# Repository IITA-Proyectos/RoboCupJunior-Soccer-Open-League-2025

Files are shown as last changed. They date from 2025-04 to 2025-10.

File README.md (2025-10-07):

# IITA - RoboCupJunior Soccer Open League 2025

Este es el repositorio del equipo IITA para la liga **Open** de RoboCupJunior Soccer 2025.

## Organización del equipo

El equipo se dividió en subgrupos de trabajo para abordar distintas áreas del desarrollo:

grupo **Movilidad**:
 - @Vale15-tb
 - @mijaelb78
 - @vickyT049

grupo **OpenMv**:
 - @3liasCo
 - @rafaelmoya2010
 - @roma1keta

grupo **Dribbler**:
 - @lauri-an
 - @xio02
 - @Aczino593

grupo **Control**:
 - @Leandro284-AR
 - @srmartbr17
 - @ASH101-CODE

Tutores:
 - @Martii3141
 - @sebalander

📌 [Falta agregar un diagrama en bloques del sistema]

---

## Referencias y recursos

### Reglas y recursos oficiales

https://junior.robocup.org/robocupjunior-general-rules/

- 📄 Reglas 2025 (versión HTML):  
  https://robocup-junior.github.io/soccer-rules/2025-soccer-draft-rules/rules.html  
- 📄 Reglas 2025 (PDF):  
  https://robocup-junior.github.io/soccer-rules/master/rules.pdf

Otros links útiles mencionados en ese documento:

- 💬 Foro: https://junior.forum.robocup.org/  
- 💬 Discord: https://robocup-junior.github.io/soccer-rules/discord/  
- 📐 Especificaciones del campo de juego:  
  https://robocup-junior.github.io/soccer-rules/master/field_specification.html

---

### Otros recursos útiles

- 🧠 Recopilación de recursos:  
  https://github.com/robocup-junior/awesome-rcj-soccer  
- 🔧 Kit open source de robótica de fútbol:  
  https://github.com/robot-soccer-kit  
- 📚 Repositorio IITA de recursos en visión y robótica:  
  https://github.com/IITA-Proyectos/resources-robotics-and-machine-vision-resources  
- 🎮 Tutoriales de fútbol virtual de Roboliga Argentina:  
  https://www.virtual.roboliga.ar/1_16_f-tbol.html
- Ejercicios de MAtematicas:
  https://mateslibres.com/
- Balogh, Richard & Obdržálek, David. (2019). Using Finite State Machines in Introductory Robotics: Methods and Applications for Teaching and Learning. 10.1007/978-3-319-97085-1_9.
- Reglas nacionales
  https://docs.google.com/document/d/10VgMxnmTzKQiAOIgHjWHb9KzwLUDc66N0ZvooTC_tL8/edit?tab=t.0

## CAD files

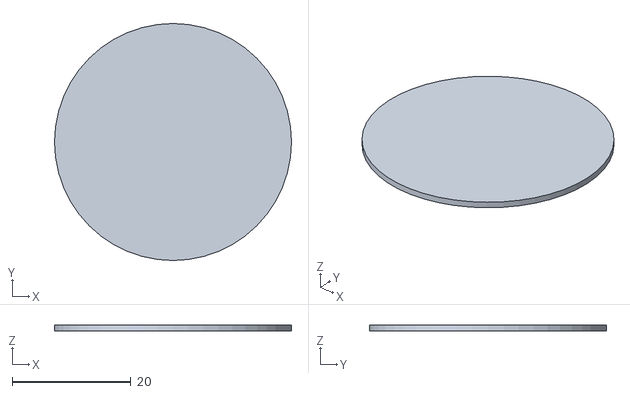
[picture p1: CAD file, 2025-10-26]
Diseño3D/Super Albar-Rottis.stl
40.0 x 40.0 x 1.00

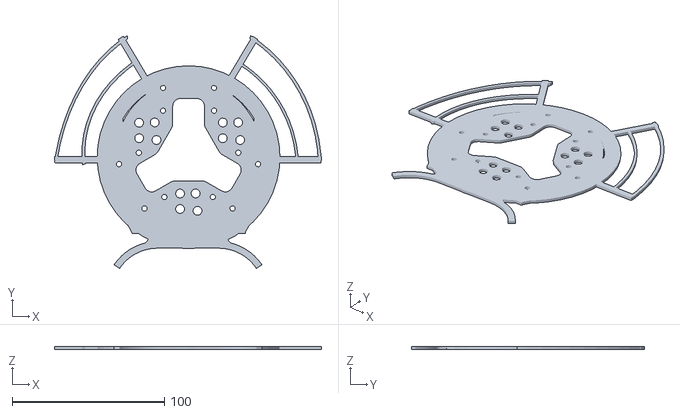
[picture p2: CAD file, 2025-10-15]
Diseño3D/Brilliant Elzing-Amberis.stl
175.2 x 152.9 x 2.00

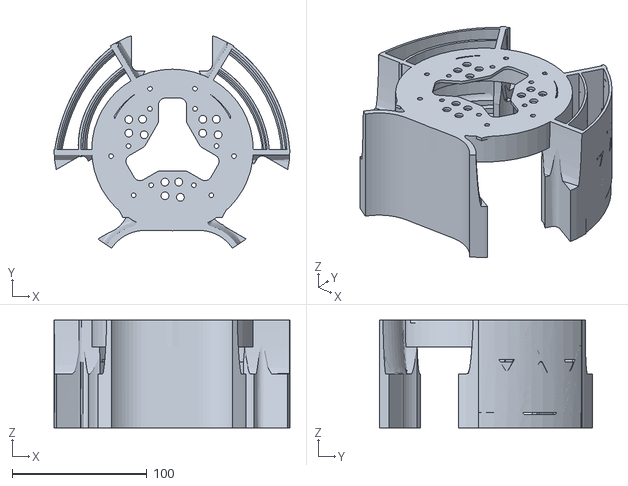
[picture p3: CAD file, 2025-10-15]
Diseño3D/Amazing Wluff (10).stl
175.2 x 157.9 x 80.0

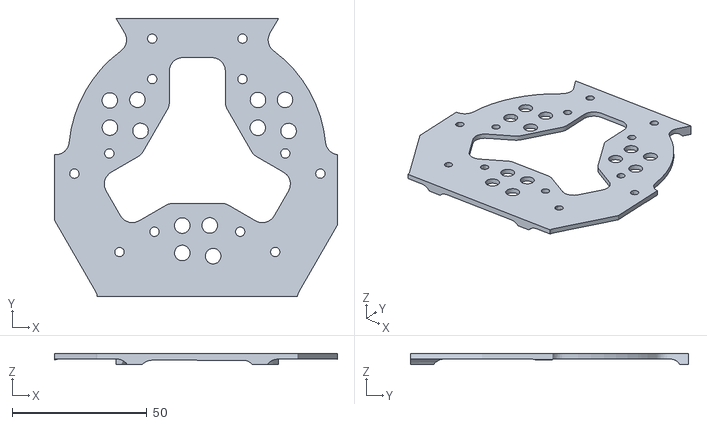
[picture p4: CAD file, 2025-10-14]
Diseño3D/Amazing Wluff (4).stl
105.0 x 103.1 x 4.00

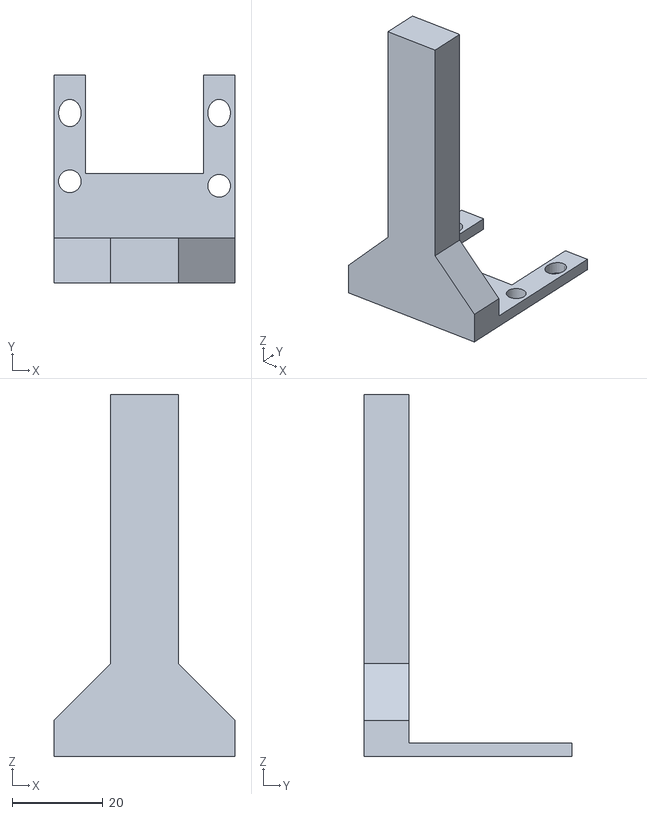
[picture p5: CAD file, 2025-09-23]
Diseño3D/Brilliant Waasa-Gaaris (1).stl
40.0 x 46.0 x 80.0

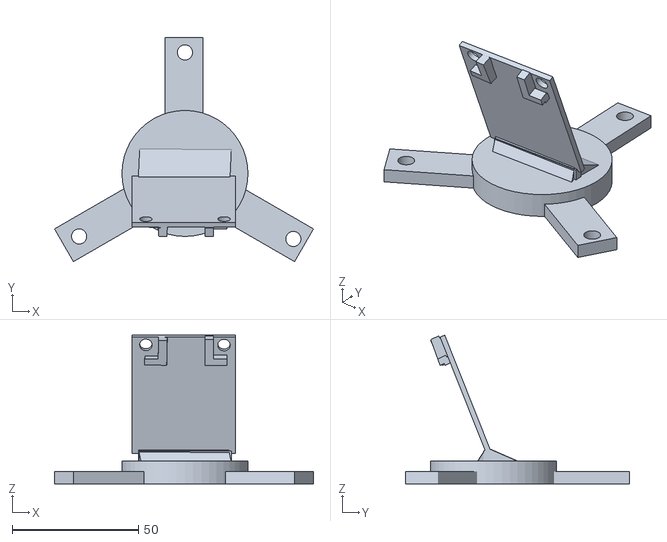
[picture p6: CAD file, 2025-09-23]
Diseño3D/Funky Elzing-Gaaris.stl
102.8 x 89.0 x 59.0

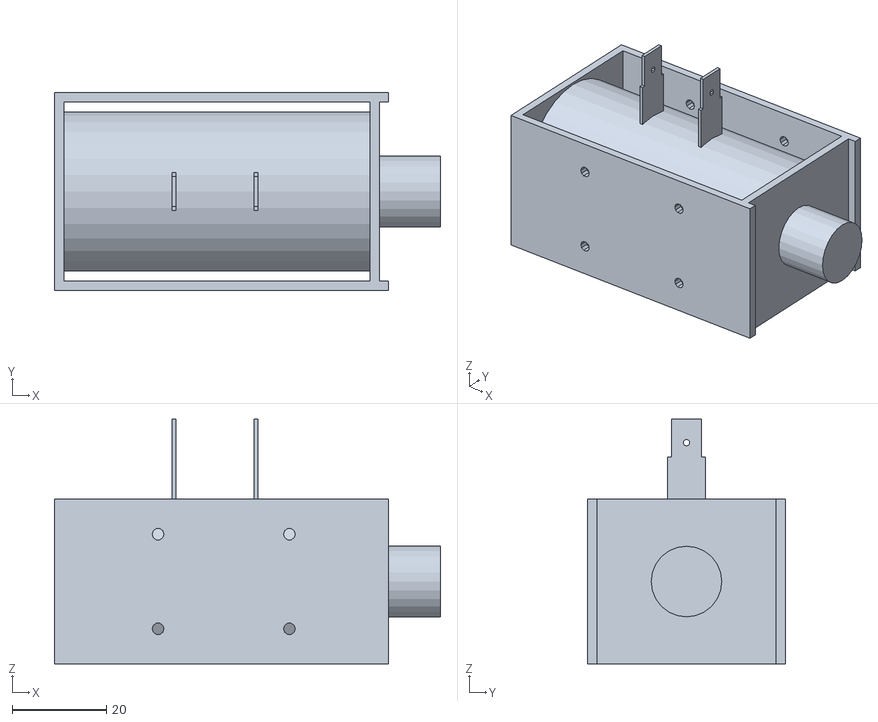
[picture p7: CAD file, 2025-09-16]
Diseño3D/solenoide.stl
82.0 x 42.0 x 52.0

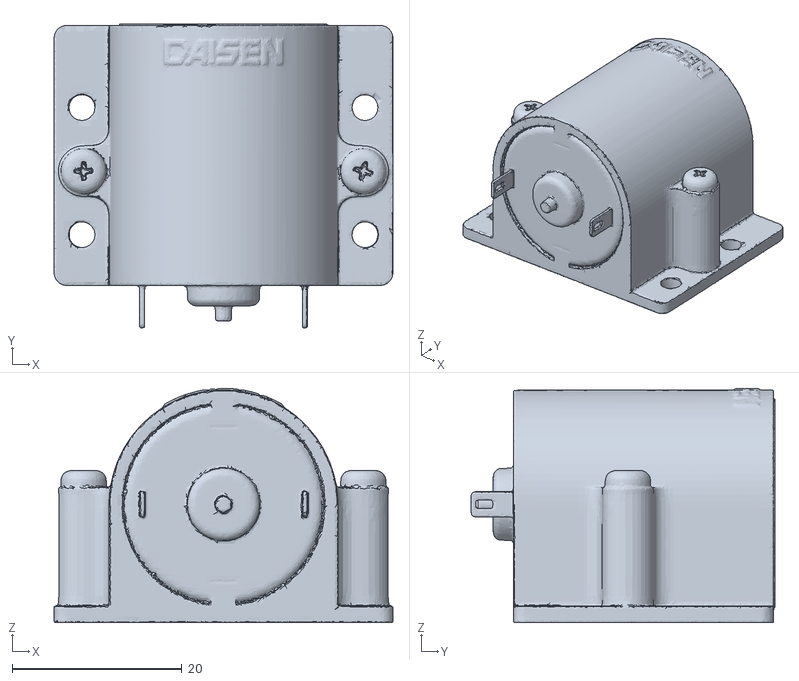
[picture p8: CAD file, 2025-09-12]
Diseño3D/motor_p_imprimir.stl
40.0 x 35.9 x 27.7

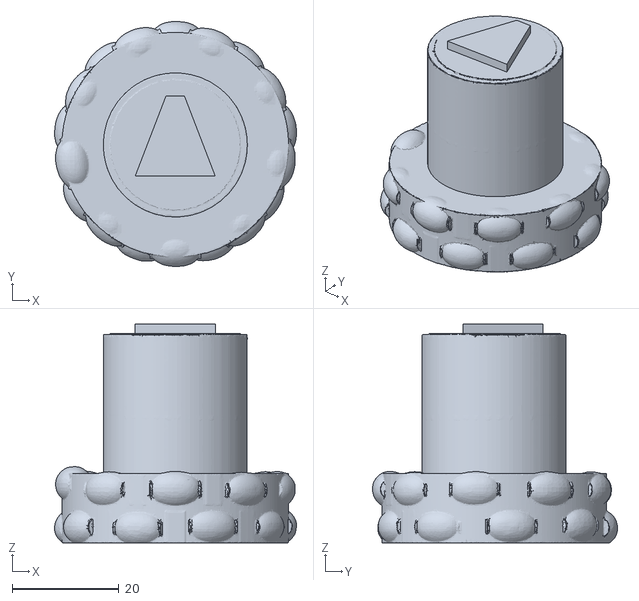
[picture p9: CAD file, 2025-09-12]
Diseño3D/rueda_p_imprimir.stl
45.3 x 45.8 x 40.9

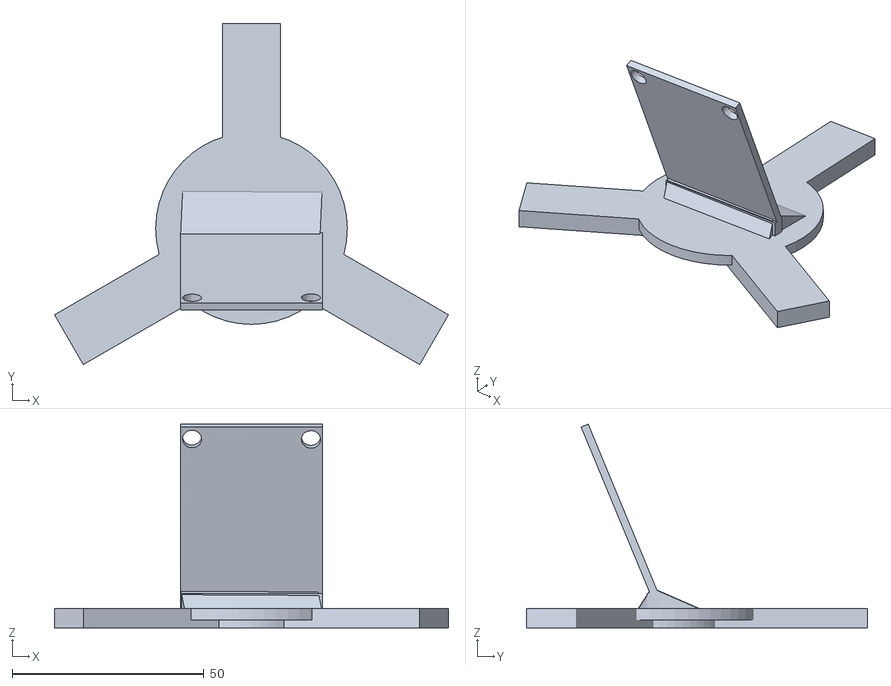
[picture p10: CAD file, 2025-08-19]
Diseño3D/Tremendous Allis.stl
102.8 x 89.0 x 53.1

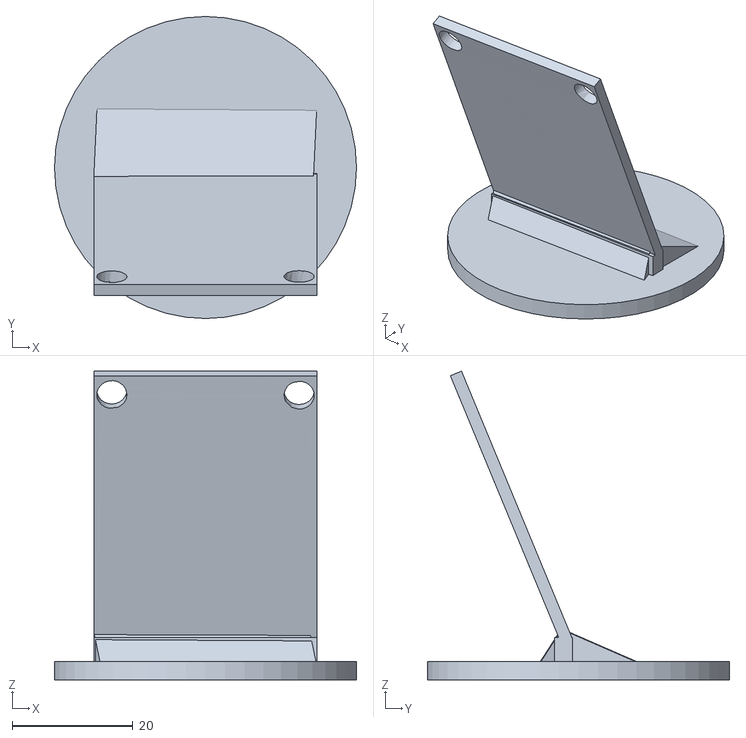
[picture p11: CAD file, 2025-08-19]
Diseño3D/union diseño de v+m.stl
50.0 x 50.0 x 51.1

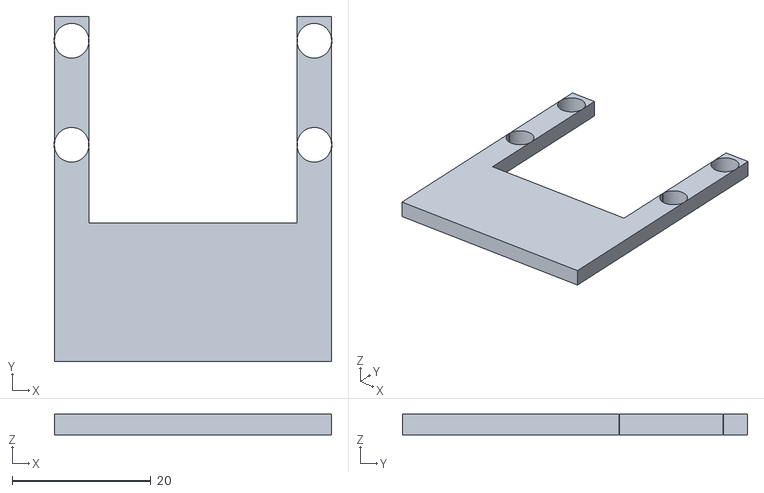
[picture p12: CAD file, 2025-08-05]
Diseño3D/Fantabulous Jaban-Turing.stl
40.0 x 49.8 x 3.00

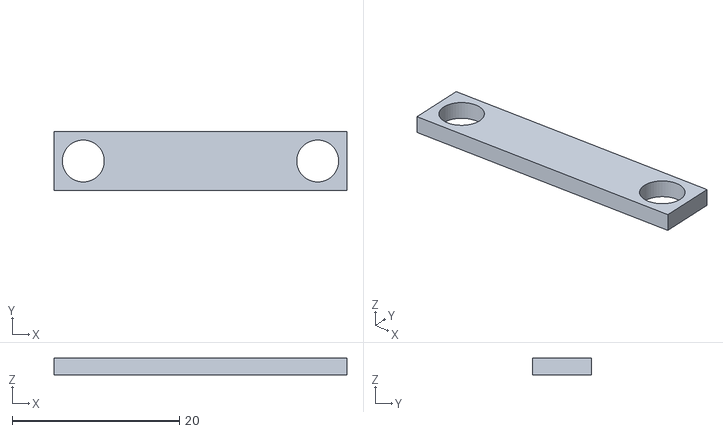
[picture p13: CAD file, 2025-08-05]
Diseño3D/Fabulous Luulia-Robo.stl
35.0 x 7.00 x 2.00

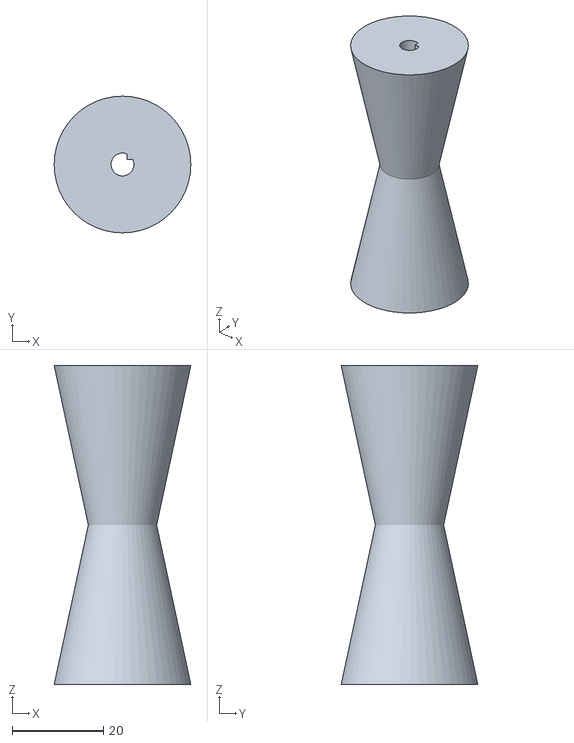
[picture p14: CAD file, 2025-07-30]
Diseño3D/Cilindro (forma de reloj de arena) con diente en el eje.stl
30.0 x 30.0 x 70.0

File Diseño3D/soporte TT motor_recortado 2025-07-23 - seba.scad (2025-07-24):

// https://www.thingiverse.com/thing:5611259
module un_soporte(){
    rotate([90,0,0])
    difference(){
    import("./TT Motor mount - 5611259/files/6VDC_motor_mount_REV2.STL");
    translate([-1,-5, 27]) cube([100, 40, 30]);
    }    
}


// https://www.thingiverse.com/thing:1079893
module motor(){
    translate([93,4,27.5])
    rotate([90,180,0]) import("./yellow TT motor - 1079893/files/DC_Motor_20mm.STL");
    }

module recortado(){
    union(){
        difference(){
            un_soporte();
            translate([4, -30, 0]) cube([5,30,7]);
            translate([0, -5, 0]) cube([53,6,20]);
            translate([40, 5, 16]) rotate([90,0,0]) cylinder(10, d=33);
        }
        
        translate([63.5, -5, 0]) cube([8, 5, 30]);
        //translate([9, -22, 0]) cube([3,5,5]);
        //translate([15, -13, 0]) cube([10,3,5]);
    }
}

//recortado();
module medio_ojal(){
    intersection(){
    translate([-11, 12.25, 0]) un_soporte();
    translate([-0.05, -6.75, 0]) cube([6.1,13.5,4]);
    }
}

module ojal(){
    union(){
        medio_ojal();
        mirror([1,0,0]) medio_ojal();
    }}

// ojal();
module soporte_sin_ojales(){
difference(){
    union(){
        translate([-10, 12.25, 0]) recortado();
        translate([-1, -10, 0]) cube([10, 15, 3]);
        translate([56, -10, 0]) cube([10, 15, 3]);
    }
    translate([-1, -8, 3]) cube([10, 15, 3]);
    translate([55, -8, 3]) cube([10, 15, 3]);
}
}
// uncomment to draw as reference only
// motor();

module punta_con_ojal(){
    intersection(){
recortado();
translate([0, -30, -1]) cube([22, 40, 7]);}
}

module soporte_sin_punta(){
    difference(){
recortado();
translate([0, -30, -1]) cube([22, 40, 7]);}
}

module soporte_nuevo(){
    union(){
soporte_sin_punta();
translate([5,0,0]) punta_con_ojal();}
}



module lego_13(){import("./13.stl");}

module lego_13_cut(){
intersection(){
translate([5, 1, 0]) lego_13();
    cube([25, 10, 10]);
}
}



// as reference a lego beam
// https://www.printables.com/model/844733-lego-technic-beams-set-1-15/files
// translate([0,-16,0]) import("./13.stl");

soporte_nuevo();

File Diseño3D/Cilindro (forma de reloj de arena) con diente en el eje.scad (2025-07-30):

union(){
    translate([-10, 21.2, -10]) import("/home/seba/Downloads/Cilindro (forma de reloj de arena).stl");

e = 1.8; // el ancho de una aletita de eje en cruz
E = 4.64; // ancho total del eje

ecc = e / 2 + 0.1; // cuanto desplazar el cubito del eje central

translate([ecc, ecc, 0]) cube([5,5,5]);
translate([ecc, ecc, 65]) cube([5,5,5]);
}

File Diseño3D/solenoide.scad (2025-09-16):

module borne(){
    rotate([0, -90, 0]) translate([-5,0,0])
union(){
difference(){
    cube([10, 6.4, 0.8], center=true);
    cylinder(1.0, d=1.4, center=true, $fn=10);
}
translate([-8-3, 0 ,0]) cube([16, 8.0, 0.8], center=true);}}


module agujerito(){
    rotate([90,0,0]) 
        cylinder(4, d=2.5, $fn=10);    
    }

module agujeritos(){
    daux = (30.5 + 25.3) / 2;
    translate([       22, 3, 6.2 + 2.5/2]) agujerito();
    translate([22 + daux, 3, 6.2 + 2.5/2]) agujerito();
    translate([       22, 3, 35 - 6.2 - 2.5/2]) agujerito();
    translate([22 + daux, 3, 35 - 6.2 - 2.5/2]) agujerito();
}

module placalateral(){
    difference(){
        cube([71.0, 2, 35]);
        agujeritos();
    }
}

module solenoide(){
    union(){
        placalateral();
        translate([0,40,0]) 
            placalateral();

        cube([2, 42, 35]); // placa de atras
        translate([67,0,0]) 
            cube([2, 42, 35]); // placa de adelante

        translate([2, 42/2, 35/2]) 
            rotate([0, 90, 0]) 
                cylinder(h=66, d=34);

        // los dos bornes
        translate([25+0.4, 21, 17+35]) borne();
        translate([25+0.8+17, 21, 17+35]) borne();

        // el eje saliendo adelante
        translate([67+15, 42/2, 35/2])
            rotate([0, -90, 0]) 
                cylinder(h=20, d=15);

    }
}

solenoide();

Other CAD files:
Diseño3D/Daring Jaagub-Fyyran.stl
Diseño3D/Grand Jaagub-Bigery.stl
Diseño3D/soporte TT motor_recortado 2025-07-23 - seba.stl
Diseño3D/2.0intentoconalturamijae3l.stl
Diseño3D/Cilindro (forma de reloj de arena).stl
Diseño3D/Cilindro (normal).stl
Diseño3D/Daring Hango-Fyyran (1).stl
Diseño3D/Dual_Servo_Bracket.stl
Diseño3D/Fabulous Lappi.stl
Diseño3D/Fantabulous Jaban-Turing (2).stl
Diseño3D/Fantabulous Jaban-Turing (4).stl
Diseño3D/Fantabulous Jaban-Turing (5).stl
Diseño3D/Funky Elzing-Gaaris (2).stl
Diseño3D/Glorious Fyyran-Fulffy.stl
Diseño3D/Grand Stantia-Turing (1).stl
Diseño3D/Ingenious Vihelmo-Esboo.stl
Diseño3D/Neat Stantia-Duup.stl
Diseño3D/Smashing Jofo.stl
Diseño3D/Terrific Albar-Bruticus (3).stl
Diseño3D/Ya-lo-toque-jaja.stl
Diseño3D/base-0.3demijael.stl
Diseño3D/estructura para los pisos.stl
Diseño3D/mijael.barra.stl

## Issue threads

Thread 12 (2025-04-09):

¡Qué alegría verte, Victoria!

sebalander, 2025-04-09:
Contá acá qué mascota te gustaría tener si pudieras elegir cualquiera (¡vale todo!) y poné una imagen de ejemplo. Después, cerrá este issue.

vickyT049, 2025-04-12:
me gustaría tener como mascota a un conejo

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

sebalander, 2025-04-14:
@vickyT049 terminaste perfectamente el issue. asi que lo podes cerrar marcandolo como completado en el boton de abajo. en ingles dice "closed as completed"

Closed 2025-04-29.

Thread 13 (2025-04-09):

¡Qué hacés, Xiomara!

sebalander, 2025-04-09:
Escribí en este issue una palabra en quechua que conozcas o hayas escuchado y explicá lo que significa. Luego marcá como resuelto.

xio02, 2025-04-15:
Haku(significa vamos)

sebalander, 2025-04-16:
buenisimo @xio02 note olvides de cerrar el issue

Closed 2025-04-22.

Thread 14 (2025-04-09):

¡Seba, querido, bienvenido a GitHub!

sebalander, 2025-04-09:
Compartí acá una foto o un meme que resuma cómo fue tu día hoy en el taller. (Cuanto más gracioso, mejor 😜).
Cuando lo hagas, marcá este issue como resuelto. ¡A disfrutar, profe!

sebalander, 2025-04-09:
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

aguante batman 🤘

Closed 2025-04-09.

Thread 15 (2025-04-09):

¡Martina, te toca a vos!

sebalander, 2025-04-09:
Comentá con el título de una película o serie que creas que representa cómo va nuestro taller de robótica hasta ahora, y explicá en una frase por qué la elegiste 🎬🤖.
Después dale click en resolver. ¡Gracias, Marti!

Martii3141, 2025-04-09:
La película es muchachos y elijo esa porque, primero creo que vamos a llegar lejos como la selección y segundo Francia

Closed 2025-04-09.

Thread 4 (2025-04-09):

¿Qué hacés, Lea?

sebalander, 2025-04-09:
Respondé en este issue con lo primero que se te venga a la mente al leer las palabras "herramienta" y "color". Después, cerrá el issue dando click en el botón.

Leandro284-AR, 2025-04-15:
Alicate naranza

Closed 2025-04-15.

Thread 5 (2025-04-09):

¡Hola, Elias! Un gustazo verte por acá

sebalander, 2025-04-09:
Pegá acá una foto del paisaje más lindo que hayas visto en Salta o en donde quieras. Una vez hecho, cerrá el issue. ¡Así de fácil!

sebalander, 2025-04-15:
beeee, no pusiste fotottt

3liasCo, 2025-04-15:
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

Closed 2025-04-15.

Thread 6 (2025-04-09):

¿Todo bien, Franco?

sebalander, 2025-04-09:
Escribí el nombre de una canción que te guste y contá en una frase cortita por qué la elegiste. Después, marcá el issue como resuelto.

Aczino593, 2025-04-15:
The line de Twenty one Pilot
La elegí por que me gusta la canción y la serie en la que sale.

Closed 2025-04-15.

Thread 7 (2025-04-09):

¡Qué tal, Lauriana!

sebalander, 2025-04-09:
Publicá acá un emoji que creas que te representa y explicá en pocas palabras por qué. Cuando termines, resolvé el issue con un click.

lauri-an, 2025-04-15:
😔: este emoji me representa porque así me siento

Closed 2025-04-29.

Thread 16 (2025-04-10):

Actividad en Clase: Armar Ruedas de Zircon

sebalander, 2025-04-10:
Estas serian las instrucciones traducidas al castellano:

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

sebalander, 2025-04-16:
@mijaelb78 @xio02 @rafaelmoya2010 si consideran que el armado de las ruedas esta termiando, marquen como compeltado el issue

xio02, 2025-04-22:
completado

Closed 2025-04-22.

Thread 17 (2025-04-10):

Actividad en Clase: soldar la electronica de la placa zircon

sebalander, 2025-04-10:
<!-- Failed to upload "IMG_20250410_140306.jpg" -->

hay que soldar todos los componentes

sebalander, 2025-04-16:
@Aczino593 @Leandro284-AR la clase que viene probablemente terminen de soldar todo. o cuando eso pase, marquen como cerrado el issue

Closed 2025-05-22.

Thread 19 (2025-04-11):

Tarea para la casa: Engranajes

sebalander, 2025-04-11:
# 📚 Teoría y Ejemplos

## Teoría
Ver este video con explicación general:
YouTube – Teoría de engranajes
https://www.youtube.com/watch?v=GDBD-B_fqgs

## Ejemplo práctico
Ver **solo los primeros 40 segundos** del siguiente video para entender un ejemplo de cálculo:
YouTube – Ejemplo de tren de engranajes
https://www.youtube.com/watch?v=QwXK4e4uqXY

# 🧠 Ejercicios

## Ejercicio 1
De esta guía de ejercicios: Ejercicios Resueltos Mecanismos - Parte 2 (p. 3/7)
https://blogsaverroes.juntadeandalucia.es/iesbellavista/files/2015/05/EJERCICIOS_RESUELTOS_MECANISMOS_PARTE_2.pdf
Resolver el ejercicio que dice  **"tren de engranajes"** en la pagina 3.

## Ejercicio 2
De esta guía:  140 Ejercicios de Engranajes
https://www.scribd.com/document/94536681/140-EJERCICIOS-DE-ENGRANAJES
Resolver el **ejercicio 11**.

sebalander, 2025-04-23:
# ✅ Seguimiento de ejercicios @Aczino593
- [ ] Video teoría visto
- [ ] Video ejemplo visto
- [ ] Tren de engranajes (p. 3)
- [ ] Ejercicio 11 - Scribd

sebalander, 2025-04-23:
# ✅ Seguimiento de ejercicios @lauri-an
- [ ] Video teoría visto
- [ ] Video ejemplo visto
- [ ] Tren de engranajes (p. 3)
- [ ] Ejercicio 11 - Scribd

sebalander, 2025-04-23:
# ✅ Seguimiento de ejercicios @xio02
- [ ] Video teoría visto
- [ ] Video ejemplo visto
- [ ] Tren de engranajes (p. 3)
- [ ] Ejercicio 11 - Scribd

Closed 2025-04-29.

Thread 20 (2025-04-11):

Tarea para la casa: Matemática de función proporcional y lineal

sebalander, 2025-04-11:
# Regla de tres simple

No busqué teoría sobre la regla de tres porque supuse que ya la conocen o sería fácil de googlear. Pero si prefieren que les recomiende algo para leer sobre teoría, avisen y lo sumo.

**Guía de ejercicios**: Problemas de Regla de Tres Simple Directa e Inversa
https://www.uv.es/jbosch/PDF/RepasoReglaTresPorcentajes.pdf

Resolver los ejercicios: **2, 5, 6 y 16** de la guía.

# Ecuación de la recta

**Blog**: Yo Soy Tu Profe – Ejercicios resueltos + video
https://yosoytuprofe.20minutos.es/2016/02/14/practica-3-ecuacion-de-la-recta/

1. Ver el video del blog.
2. Resolver los **tres ejercicios propuestos** que aparecen debajo del video.

sebalander, 2025-04-23:
# ✅ Seguimiento de ejercicios @3liasCo
 - [ ] Regla de tres - Ejercicio 2
 - [ ] Regla de tres - Ejercicio 5
 - [ ] Regla de tres - Ejercicio 6
 - [ ] Regla de tres - Ejercicio 16
 - [ ] Ecuación de la recta - Ej. 1
 - [ ] Ecuación de la recta - Ej. 2
 - [ ] Ecuación de la recta - Ej. 3

sebalander, 2025-04-23:
# ✅ Seguimiento de ejercicios @roma1keta
 - [ ] Regla de tres - Ejercicio 2
 - [ ] Regla de tres - Ejercicio 5
 - [ ] Regla de tres - Ejercicio 6
 - [ ] Regla de tres - Ejercicio 16
 - [ ] Ecuación de la recta - Ej. 1
 - [ ] Ecuación de la recta - Ej. 2
 - [ ] Ecuación de la recta - Ej. 3

sebalander, 2025-04-23:
@roma1keta , reabrí el issue para que @3liasCo y @rafaelmoya2010 puedan hacerle check a los ejercicios que ya hicieron.

cuando los tres terminen de hacer todos los ejercicios, ahi si cierren en issue

sebalander, 2025-04-23:
# ✅ Seguimiento de ejercicios @Vale15-tb
 - [ ] Regla de tres - Ejercicio 2
 - [ ] Regla de tres - Ejercicio 5
 - [ ] Regla de tres - Ejercicio 6
 - [ ] Regla de tres - Ejercicio 16
 - [ ] Ecuación de la recta - Ej. 1
 - [ ] Ecuación de la recta - Ej. 2
 - [ ] Ecuación de la recta - Ej. 3

sebalander, 2025-04-23:
# ✅ Seguimiento de ejercicios @mijaelb78
 - [ ] Regla de tres - Ejercicio 2
 - [ ] Regla de tres - Ejercicio 5
 - [ ] Regla de tres - Ejercicio 6
 - [ ] Regla de tres - Ejercicio 16
 - [ ] Ecuación de la recta - Ej. 1
 - [ ] Ecuación de la recta - Ej. 2
 - [ ] Ecuación de la recta - Ej. 3

sebalander, 2025-04-23:
# ✅ Seguimiento de ejercicios @vickyT049
 - [ ] Regla de tres - Ejercicio 2
 - [ ] Regla de tres - Ejercicio 5
 - [ ] Regla de tres - Ejercicio 6
 - [ ] Regla de tres - Ejercicio 16
 - [ ] Ecuación de la recta - Ej. 1
 - [ ] Ecuación de la recta - Ej. 2
 - [ ] Ecuación de la recta - Ej. 3

sebalander, 2025-04-23:
@Vale15-tb, @mijaelb78, @vickyT049 Los agregue al issue porque esta teoria les va a servir para la calibracion de los movimientos lineal y de giro del robot

sebalander, 2025-05-07:
veo que todos ya hiciero todo o casi todos los ejercicios, asi que ya  eta bien apra cerrarlo.

Closed 2025-05-07.

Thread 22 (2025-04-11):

Arduino - Ejemplo Control Monitor Serie - Grupos: Movilidad y Control

Martii3141, 2025-04-11:
Copiar y pegar el siguiente codigo en TinkerCad y ejecutarlo.
Obetivo de la Guia: Analizar las nuevas funciones del monitor serie que son presentadas (read, parseInt, available, etc). Observar funciones creadas por el usuario y su invocacion.
Actividad: Hacer un seguimiento de la variable actividadActual y poder saber en todo momento cual es su valor.

`
	//Guia Monitor Serie Arduino

	//Declaracion de vbles globales		Las Variables Globales son variables que se declaran fuera del loop, del setup y de cualquier otra funcion creada por el usuario. Dichas variables se les conoce como globales, ya que se pueden invocar en cualquiera de las otras funciones
	String nombre = "";			//Los tipos de datos String son una concatenacion de caracteres.
	int actividadActual;
	int edad;
	int respuesta;
	String despedida = "chau";
	bool tutorial = true;

	void setup(){
		Serial.begin(9600);		//Esta linea sirve para inicializar el monitor serie. Sin esta linea, no podremos usar tal herramienta. El argumento de 9600, nos indica la tasa de transferencia de datos. No es el unico valor que puede tener de transferencia de datos, pero por ahora solo usaremos este.
		Serial.println("******************************************************");	//Las funcion print y println del monitor Serial, nos sirven para imprimir texto o valores de vbles. La unica diferencia entre print y println es que println agrega un renglon al final de todo el texto impreso en dicha linea.
		Serial.println("* Bienvenidxs a la guia del Monitor Serie de Arduino *");
		Serial.println("****************************************************** \n");	//Otra forma de indicar que queremos un salto de renglon es poniendo \n en donde deseamos que se produzca dicho salto.
		Serial.println("Para continuar, envia como te llamas desde el monitor serie.");
		while(Serial.available() == 0){			//La funcion available verifica cuantos caracteres hay disponibles para ser leidos por la maquina. Es decir que en un momento inicial no hay caracteres para ser leidos (Serial.available = 0), una vez que enviamos un mensaje Serial.available() deja de ser 0, ya que tiene caracteres por leer aun.

		}
		nombre = Serial.readString();		//La funcion read lee los caracteres disponibles que hay en el monitor serie, y en este caso, los guarda en la variable nombre. Al leer los caracteres que estaban disponibles, Serial.available(), volvera a ser 0, ya que los datos que estaban disponibles ya fueron leidos con la funcion de esta linea.
		Serial.print("\n Hola ");
		Serial.print(nombre);
		Serial.println(".");
	}

	void loop(){
		mostrarConsigna();
	}

	void mostrarConsigna(){
		Serial.print("---- Actividad Nro ");
		Serial.print(actividadActual + 1);
		Serial.println(" ----");
		switch(actividadActual){			//La estructura switch case, nos sirve para asignar bloques de codigo segun valores especificos de una sola variable. Es decir, le damos una variable, la cual tomara distintos valores, y para cada valor, ejecutara una secuencia de lineas de codigo especificadas. La sintaxis es la presentada en el ejemplo. Para mas informacion, ingresar a la pagina oficial de arduino.
			case 0:					//Si la variable vale 0, entonces se ejecuta todo lo de abajo, hasta break;
			  Serial.println("Ingresa tu edad: ");
			  procesamientoEntrada();
			  break;
			case 1:					//Si la variable vale 1, entonces se ejecuta todo lo de abajo, hasta break;
			  Serial.println("¿Tu edad es un numero par o impar? \t \t 1 - Impar \t 2 - Par");
			  Serial.println("Ingresar el numero de la respuesta que corresponda (1 o 2)");
			  procesamientoEntrada();
			case 2:					//Si la variable vale 2, entonces se ejecuta todo lo de abajo hasta break;
			  Serial.println("Finaliza esta guia escribiendo y enviando 'chau' al monitor serie.");
			  procesamientoEntrada();
			  break;
		}
	return;
	}

	void procesamientoEntrada(){
		while(!tutorial){

		}
		while(Serial.available() == 0){

		}
		switch (actividadActual){
			case 0:
			  edad = Serial.parseInt();			//La funcion parseInt sirve para leer un dato entero ingresado por el monitor serie. A diferencia de read, este nos lee el dato como lo ingresamos y no en el sistema ASCII.
			  Serial.print("Tu edad es: ");
			  Serial.println(edad);
			  if(edad >= 18){
				  Serial.println("Sos mayor de edad.");
			  }
			  else{
				  Serial.println("Sos menor de edad.");
			  }
			  actividadActual++;		//Esta linea le suma 1 a la variable actividadActual. Es una forma compacta de escribir actividadActual = actividadActual + 1. Se puede hacer lo mismo con una variable para restarle 1, intercambiando el ++ por --.
			  mostrarConsigna();
			  break;
			case 1:
			  respuesta = Serial.parseInt();
			  if(respuesta == 2 && edad % 2 == 0){
			  	Serial.println("Tienes razon. Tu edad es numero par.");
			  }
		  else if(respuesta == 1 && edad % 2 == 0){
				Serial.println("Respuesta incorrecta. Tu edad si es un numero par.");
			  }
			  else if(respuesta == 1 && edad % 2 != 0){
			  	Serial.println("Respuesta correcta. Tu edad es un numero impar.");
			  }
			  else if(respuesta == 1 && edad % 2 == 0){
				Serial.println("Tienes razon. Tu edad es un numero impar.");
			  }
			  actividadActual++;
			  mostrarConsigna();
			  break;
			case 2:
			  if(Serial.readString() == despedida){
			  	Serial.println("El tutorial ha finalizado.");
				tutorial = !tutorial;
			  }
		}
	return;
	}
`

sebalander, 2025-05-03:
Marcar si ya lo completaron:

- [ ] @ASH101-CODE Compeltado
- [ ] @Leandro284-AR Completado
- [ ] @srmartbr17 Completado

sebalander, 2025-05-07:
ya todos lo completaron asi que cierro el issue

Closed 2025-05-07.

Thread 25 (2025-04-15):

logica para saber el angulo de la pelota con respecto al eje de la camara

rafaelmoya2010, 2025-04-15:
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

rafaelmoya2010, 2025-04-15:
h azul es distinta de h negra

sebalander, 2025-04-16:
esta bien, les queda como tarea (usen este mismo issue) para construir la logica, tipo pseudocodigo, o por lo menos escrita en palabras en castellano, de lo que tiene que hacer el algoritmo que calcula. recuerden:

- Inputs: las coordenadas x,y de la pelota en pixeles, son coordenadas en la imagen
- Output: cuantos radianes debe girar el robot para que la pelota quede centrada en la imagen
- Parametros: d? k? esto definanlo uds

sebalander, 2025-05-03:
hola gente. @3liasCo    @rafaelmoya2010     @roma1keta . No estoy seguro pero me parece que quiza esto ya quedo resuelto, no? o sea, recuerdo que (corrijanme si me equivoco) ya estan sabiendo como hacer la cuenta y ya estan trabajando para tenerla andando en la OpenMV, no? si es asi, pueden cerrar este issue tranquilamente. saludos

3liasCo, 2025-05-03:
Ya lo estamos usando, así que creo que ya no sirve tener la lógica bien escrita

Closed 2025-05-03.

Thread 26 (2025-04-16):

Python Basico e Introduccion a Objetos

Martii3141, 2025-04-16:
## **Google Colab de Python basico**

En resumen este documento de Google les muestra como es la sintaxis basica de Python con las diferentes funciones como el _if... else_, _while_, etc.

https://colab.research.google.com/github/carlosalvarezh/Pensamiento_Algoritmico/blob/main/Modulo04_EstructurasControlFlujo.ipynb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

## **Google Colab de Programacion Orientada a Objetos (POO) en Ingles**

Este documento es del mismo formato que el anterior, solo que este tutorial está en ingles. Si pueden leerlo, entenderlo y resolverlo genial. Sino esta el siguiente link que es documentacion en español.

https://colab.research.google.com/github/QuantEcon/lecture-python-programming.notebooks/blob/master/python_oop.ipynb

## **Tutorial POO en español**

Este tutorial es de la pagina ellibrodepython.com que esta buena por si quieren chequear mas cosas de python y seguir aprendiendo por su cuenta. En esta ocasion la vamos a usar para aprender lo basico de Programacion Orientada a Objetos.

https://ellibrodepython.com/metodos-estaticos-clase-python

sebalander, 2025-04-23:
# ✅ Seguimiento de ejercicios @3liasCo
 - [ ] Python Basico
 - [ ] Python POO

sebalander, 2025-04-23:
# ✅ Seguimiento de ejercicios @rafaelmoya2010
 - [ ] Python Basico
 - [ ] Python POO

sebalander, 2025-04-23:
# ✅ Seguimiento de ejercicios @roma1keta
 - [ ] Python Basico
 - [ ] Python POO

Closed 2025-05-06.

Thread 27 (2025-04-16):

Tarea para la Casa: Corregir Codigo Ejemplo Monitor Serie

Martii3141, 2025-04-16:
Como se habran dado cuenta, el codigo que les pasé, al finalizar el tutorial, les pide nuevamente que envien 'chau' por el monitor serie y luego de eso no hace mas nada el codigo.
La actividad que tienen es corregir dicho error; cuando envien 'chau', lo ultimo que tiene que mostrar el monitor serie es "El tutorial ha finalizado."

## **Recomendaciones**
- Traten de primero entender porque ocurre lo del codigo original. Para esto tienen que poder entender la gran mayoria del codigo que esta escrito.
- Consulten las partes del codigo que no entiendan, que les generen duda de porque se hizo de tal forma, etc.
- Modifiquen el codigo o hagan otros codigos de prueba para tratar de entender mejor las funciones que se estan usando.

##
**Las dudas, como asi tambien el codigo corregido mandenlo por los comentarios de este issue.**
##

sebalander, 2025-04-23:
✅ Seguimiento de ejercicios @Leandro284-AR
- [ ] Codigo Corregido

sebalander, 2025-04-23:
✅ Seguimiento de ejercicios @srmartbr17
- [ ] Codigo Corregido

sebalander, 2025-04-23:
✅ Seguimiento de ejercicios @ASH101-CODE
- [ ] Codigo Corregido

Leandro284-AR, 2025-04-27:
// Declaración de variables globales
String nombre = "";
int actividadActual;
int edad;
int respuesta;
String despedida = "chau";
bool tutorial = true;

void setup() {
  Serial.begin(9600);
  Serial.println("******************************************************");
  Serial.println("* Bienvenidxs a la guia del Monitor Serie de Arduino *");
  Serial.println("****************************************************** \n");
  Serial.println("Para continuar, envia como te llamas desde el monitor serie.");

  while (Serial.available() == 0) {
    // Esperar nombre
  }

  nombre = Serial.readString();
  Serial.print("\n Hola ");
  Serial.print(nombre);
  Serial.println(".");
}

void loop() {
  if (tutorial) {
    mostrarConsigna();
  } else {
    // Detiene el loop completamente para que no haga nada más
    while (true);
  }
}

void mostrarConsigna() {
  Serial.print("---- Actividad Nro ");
  Serial.print(actividadActual + 1);
  Serial.println(" ----");

  switch (actividadActual) {
    case 0:
      Serial.println("Ingresa tu edad: ");
      procesamientoEntrada();
      break;
    case 1:
      Serial.println("¿Tu edad es un numero par o impar? \t \t 1 - Impar \t 2 - Par");
      Serial.println("Ingresar el numero de la respuesta que corresponda (1 o 2)");
      procesamientoEntrada();
      break;
    case 2:
      Serial.println("Finaliza esta guia escribiendo y enviando 'chau' al monitor serie.");
      procesamientoEntrada();
      break;
  }
}

void procesamientoEntrada() {
  while (!tutorial) {
    // No hacemos nada si el tutorial ya terminó
  }

  while (Serial.available() == 0) {
    // Esperar entrada
  }

  switch (actividadActual) {
    case 0:
      edad = Serial.parseInt();
      Serial.print("Tu edad es: ");
      Serial.println(edad);
      if (edad >= 18) {
        Serial.println("Sos mayor de edad.");
      } else {
        Serial.println("Sos menor de edad.");
      }
      actividadActual++;
      break;

    case 1:
      respuesta = Serial.parseInt();
      if (respuesta == 2 && edad % 2 == 0) {
        Serial.println("Tienes razón. Tu edad es número par.");
      } else if (respuesta == 1 && edad % 2 == 0) {
        Serial.println("Respuesta incorrecta. Tu edad sí es un número par.");
      } else if (respuesta == 1 && edad % 2 != 0) {
        Serial.println("Respuesta correcta. Tu edad es un número impar.");
      } else if (respuesta == 2 && edad % 2 != 0) {
        Serial.println("Respuesta incorrecta. Tu edad no es un número par.");
      }
      actividadActual++;
      break;

    case 2:
      String entrada = Serial.readString();
      entrada.trim();  // Quita espacios y saltos de línea
      if (entrada == despedida) {
        Serial.println("El tutorial ha finalizado.");
        tutorial = false;
      } else {
        Serial.println("No entendi eso. Por favor, escribe 'chau' para salir.");
      }
      break;
  }
}

Closed 2025-05-22.

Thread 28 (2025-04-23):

checkboxes test

sebalander, 2025-04-23:
# @sebalander
 - [ ] Video teoría visto
 - [ ] Video ejemplo visto
 - [x] Tren de engranajes (p. 3)
 - [ ] Ejercicio 11 - Scribd

# @Martii3141
 - [ ] Video teoría visto
 - [ ] Video ejemplo visto
 - [x] Tren de engranajes (p. 3)
 - [ ] Ejercicio 11 - Scribd

sebalander, 2025-04-23:
parece que hayq ue usar este formato en listas para que el chequeo persista

Closed 2025-04-23.

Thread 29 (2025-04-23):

Movilidad: calibrar factor de tiempo para movimiento lineal y de giro en el lugar

sebalander, 2025-04-23:
@Vale15-tb , @mijaelb78 , @vickyT049 ayer Uds. tomaron una tablita de datos donde estaba el tiempo de delay en una columna, el angulo que efectivamente giro el robot en otra columna. o tambien habia una tercera columna con el angulo de giro deseado, no?

todo ese trabajo de calibracion es importante que lo documenten. asi que en este issue suban los datos que tomaron, y tambien si hay fotos o alguna otra cosa. es para que la informacion que tomaron ayer quede bien documentada y a futuro nos sirva de referencia.

Vale15-tb, 2025-04-28:
[

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

Closed 2025-04-28.

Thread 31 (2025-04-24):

Aprender Funciones Arduino

Martii3141, 2025-04-24:
# 📚 Lectura sobre Funciones

¡Hola a todos! Antes de empezar con la actividad práctica, es importante que leamos un poco sobre qué son las funciones en programación. Esto nos dará una base para entender por qué son tan útiles.

Aquí les dejo un link con información sobre funciones en C++ (el lenguaje que usamos en Arduino):

[Concepto de Funciones en C++](https://www2.eii.uva.es/fund_inf/cpp/temas/8_funciones/funciones.html)

---

# ✨ ¿Por qué usar Funciones?

Como leyeron en el enlace, las funciones son bloques de código que hacen una tarea específica. Son súper útiles porque nos permiten no tener que estar reescribiendo el mismo código una y otra vez. Si tenemos que hacer algo varias veces en nuestro programa, ¡creamos una función para eso y listo!

Aquí tienen un ejemplo sencillo de cómo se ven las funciones en Arduino, usando solo el Monitor Serie:
Aqui tienen dos ejemplos de codigo que simulan lectura de sensores. Al ejecutar los codigos, ambos hacen lo mismo. La diferencia es que en uno usamos funciones propias, mientras que en el otro no usamos funciones propias. La idea es que puedan ver que a veces nos facilita la escritura del codigo cuando las tareas a hacer son similares, solo cambiando en este caso, el sensor que vamos a leer y procesar dicha lectura.

```C++
// Codigo Con Funciones Creadas por el usuario

//Variables
int sensor1 = 1;
int sensor2 = 2;
int sensor3 = 3;
int lectura1;
int lectura2;
int lectura3;
int procesado1;
int procesado2;
int procesado3;

int leerSensor(int sensor){
	Serial.println("\n--- Leyendo Sensor ---");
	long valor = random(0,100);	//Simulamos una lectura con la funcion random(), que no genera un valor aleatorio.
	Serial.print("  Valor leido: ");
	Serial.println(valor);

	return valor;
}

int procesarLectura(int sensor, long lectura){
	int procesado = lectura * 2; //Simulamos un procesamiento
	Serial.print("Sensor ");
	Serial.print(sensor);
	Serial.println(":");
	Serial.println("------- Reporte -------");
    Serial.print("  Valor Leido: ");
    Serial.println(lectura);
    Serial.print("  Valor Procesado: ");
    Serial.println(procesado);
    Serial.println("-------------------------");

    return procesado;
}

void resumen (int resumen1, int resumen2, int resumen3){
	// --- Resumen Final ---
    Serial.println("\n--- Resumen Final ---");
    Serial.println("Resultados Procesados:");
    Serial.print("  Sensor 1: ");
    Serial.println(resumen1);
    Serial.print("  Sensor 2: ");
    Serial.println(resumen2);
    Serial.print("  Sensor 3: ");
    Serial.println(resumen3);
    Serial.println("-------------------------");
}

void setup() {
  Serial.begin(9600); // Inicializamos el Monitor Serie
  // --- Inicio del Sistema ---
  Serial.println("--- Sistema Iniciado ---");
  Serial.println("Envia cualquier mensaje por el monitor serie para iniciar el proceso.");
  Serial.println("-------------------------");
}

void loop() {
    while (Serial.available() == 0) {
    	//Espera hasta que el usuario envie algo por el monitor serie
    	}
    lectura1 = leerSensor(sensor1);
    procesado1 = procesarLectura(sensor1, lectura1);
    lectura2 = leerSensor(sensor2);
    procesado2 = procesarLectura(sensor2, lectura2);
    lectura3 = leerSensor(sensor3);
    procesado3 = procesarLectura(sensor3, lectura3);
    resumen(procesado1, procesado2, procesado3);
    while(true){
      //Detiene el codigo
    }
}
```

```C++

// Codigo Sin Funciones Creadas por el Usuario

//Variables
int sensor1 = 1;
int sensor2 = 2;
int sensor3 = 3;
int lectura1;
int lectura2;
int lectura3;
int procesado1;
int procesado2;
int procesado3;

void setup() {
  Serial.begin(9600); // Inicializamos el Monitor Serie
  // --- Inicio del Sistema ---
  Serial.println("--- Sistema Iniciado ---");
  Serial.println("Envia cualquier mensaje por el monitor serie para iniciar el proceso.");
  Serial.println("-------------------------");
}

void loop() {
  // Espera hasta que el usuario envie algo por el monitor serie
  while (Serial.available() == 0) {
    // No hace nada, solo espera
  }

  // --- Proceso para Sensor 1 (sin usar funciones) ---
  Serial.println("\n--- Leyendo Sensor ---");
  long valor_s1 = random(0,100);    // Simulamos una lectura
  Serial.print("  Valor leido: ");
  Serial.println(valor_s1);
  lectura1 = valor_s1; // Guardamos la lectura en la variable global

  int procesado_s1 = lectura1 * 2; // Simulamos un procesamiento
  Serial.print("Sensor ");
  Serial.print(sensor1);
  Serial.println(":");
  Serial.println("------- Reporte -------");
  Serial.print("  Valor Leido: ");
  Serial.println(lectura1);
  Serial.print("  Valor Procesado: ");
  Serial.println(procesado_s1);
  Serial.println("-------------------------");
  procesado1 = procesado_s1; // Guardamos el resultado procesado en la variable global

  // --- Proceso para Sensor 2 (sin usar funciones) ---
  Serial.println("\n--- Leyendo Sensor ---");
  long valor_s2 = random(0,100);    // Simulamos una lectura
  Serial.print("  Valor leido: ");
  Serial.println(valor_s2);
  lectura2 = valor_s2; // Guardamos la lectura en la variable global

  int procesado_s2 = lectura2 * 2; // Simulamos un procesamiento
  Serial.print("Sensor ");
  Serial.print(sensor2);
  Serial.println(":");
  Serial.println("------- Reporte -------");
  Serial.print("  Valor Leido: ");
  Serial.println(lectura2);
  Serial.print("  Valor Procesado: ");
  Serial.println(procesado_s2);
  Serial.println("-------------------------");
  procesado2 = procesado_s2; // Guardamos el resultado procesado en la variable global

  // --- Proceso para Sensor 3 (sin usar funciones) ---
  Serial.println("\n--- Leyendo Sensor ---");
  long valor_s3 = random(0,100);    // Simulamos una lectura
  Serial.print("  Valor leido: ");
  Serial.println(valor_s3);
  lectura3 = valor_s3; // Guardamos la lectura en la variable global

  int procesado_s3 = lectura3 * 2; // Simulamos un procesamiento
  Serial.print("Sensor ");
  Serial.print(sensor3);
  Serial.println(":");
  Serial.println("------- Reporte -------");
  Serial.print("  Valor Leido: ");
  Serial.println(lectura3);
  Serial.print("  Valor Procesado: ");
  Serial.println(procesado_s3);
  Serial.println("-------------------------");
  procesado3 = procesado_s3; // Guardamos el resultado procesado en la variable global

  // --- Resumen Final (sin usar funciones) ---
  Serial.println("\n--- Resumen Final ---");
  Serial.println("Resultados Procesados:");
  Serial.print("  Sensor 1: ");
  Serial.println(procesado1);
  Serial.print("  Sensor 2: ");
  Serial.println(procesado2);
  Serial.print("  Sensor 3: ");
  Serial.println(procesado3);
  Serial.println("-------------------------");

  // Detiene el codigo despues de una ejecucion
  while(true){
    // No hace nada, el programa se detiene aqui
  }
}

```

# 🚀 Actividad: ¡Crea Tu Propia Función!

Ahora que viste el ejemplo, es tu turno de practicar.

**Tu Misión:**

1. Copia el código de mas abajo y ejecutalo en TinkerCad.

2. Trata de entender que hace el codigo e identifica que partes podrias reescribir en forma de funciones para no reescribir tanto codigo.

3. Asi como en el ejemplo que tienen, reescriban el codigo para que haga lo mismo que el original, solo que usando funciones creadas por ustedes mismos. Pueden agregar variables y demas cosas que necesiten. La idea es que la ejecucion sea igual, y como siempre hay distintas formas de llegar a lo mismo.

4. Subi el codigo como comentario de este issue asi nos mostras como lo hiciste.

```C++
//Variables
int numero1 = 0;
int numero2 = 0;

void setup() {
  Serial.begin(9600); // Inicializamos el Monitor Serie
  Serial.println("--- Inicio del Programa de Suma ---");
  delay(1500);
}

void loop() {
  Serial.println("\n--- Ingresa el Primer Numero ---");
  Serial.println("Debe ser mayor a 10.");

  // Bucle para obtener y validar el primer numero
    while (Serial.available() == 0) {
      // Espera a que el usuario escriba algo
    }
	numero1 = Serial.parseInt();
    while (numero1 < 10) {
      // Numero no valido, pedimos de nuevo
      Serial.println("ERROR: El numero debe ser mayor a 10.");
      Serial.println("Por favor, ingresa el Primer Numero de nuevo.");
      numero1 = Serial.parseInt();
    }
     Serial.println("Valor ingresado correctamente.");

  Serial.println("\n--- Ingresa el Segundo Numero ---");
  Serial.println("Debe ser mayor a 10.");

  // Bucle para obtener y validar el segundo numero
    while (Serial.available() == 0) {
      // Espera a que el usuario escriba algo
    }
	numero2 = Serial.parseInt();
    while (numero2 < 10) {
      // Numero no valido, pedimos de nuevo
      Serial.println("ERROR: El numero debe ser mayor a 10.");
      Serial.println("Por favor, ingresa el Primer Numero de nuevo.");
      numero2 = Serial.parseInt();
    }
     Serial.println("Valor ingresado correctamente.");

  // Ambos numeros son validos, procedemos a sumar y mostrar
  Serial.println("\n--- Calculando Suma ---");
  int resultadoSuma = numero1 + numero2;
  Serial.print("La suma de ");
  Serial.print(numero1);
  Serial.print(" y ");
  Serial.print(numero2);
  Serial.print(" es: ");
  Serial.println(resultadoSuma);
  Serial.println("-----------------------");

  Serial.println("\n--- Proceso Finalizado ---");
  // El loop() terminara y volvera a empezar, esperando la proxima entrada
}

```

###

✅ Seguimiento de ejercicios @Leandro284-AR
- [x] Lectura
- [ ] Reescribir Codigo

✅ Seguimiento de ejercicios @srmartbr17
- [ ] Lectura
- [ ] Reescribir Codigo

✅ Seguimiento de ejercicios @ASH101-CODE
- [ ] Lectura
- [ ] Reescribir Codigo

✅ Seguimiento de ejercicios @Vale15-tb
- [x] Lectura
- [ ] Reescribir Codigo

✅ Seguimiento de ejercicios @mijaelb78
- [x] Lectura
- [ ] Reescribir Codigo

✅ Seguimiento de ejercicios @vickyT049
- [x] Lectura
- [ ] Reescribir Codigo

sebalander, 2025-05-22:
@Leandro284-AR @srmartbr17 @ASH101-CODE @Vale15-tb @vickyT049 vean si vale la pena terminar este issue. la idea era que les sirva para aprender arduino. si ya no sirve mas, lo cerremos y listo. comenten mas abajo cada uno que opina asi decidimos entre todos

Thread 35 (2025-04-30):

Lista de Materiales para terminar de soldar las Zircon

Martii3141, 2025-04-30:
La tarea va a consistir en que miren el tutorial, hasta el final, de como armar las bases moviles Zircon y enlistar las cosas que van a necesitar para poder terminar con la soldadura y armado de las bases.
Link al tutorial: https://robomov.net/blogs/zircon-tutorial?page=1
Por ahora la lista consta de:
- [x] Alicate
- [x] Estaño 0.7mm
- [x] Tester
- El resto de cosas agreguenla en los comentarios de este issue. En lo posible, terminen la lista con algo de tiempo, asi nos da tiempo a conseguir los materiales.

sebalander, 2025-05-07:
ya se consiguieron los materiales asi que listo.

Closed 2025-05-07.

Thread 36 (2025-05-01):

Cortar el panel lego y definir material es para adherir a Zircon

sebalander, 2025-05-01:
Al final de la clase del martes falto que:

# definan donde cortar el panel amarillo

**Objetivo: indicar a @sebalander como cortar el panel amarillo de Legos. Las indicaciones deben ser un diagrama (dibujo, imagen, etc) bien claro indicando donde cortar y ademas pasar en texto aparte las medidas de donde se deberia cortar. por favor si tienen dudas o no saben como hacer: escriban, pregunten, etc**. Contesten en este issue un comentario con ese contenido.

Seguramente necesiten buscar informacion en internet sobre el panel. les paso una ayuda por si les sirve:  "yellow lego Technic, Panel Plate 11 x 19"

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

tambien supongo que necsitaran informacion sobre la base movil: "Robomov Zircon"

# Definir materiales para adherir/fijar el panel amarillo a la base Zircon

Objetivo: proponer una lista de materiales que servirian para fijar el panel amarillo de lego a la base de zircon. Comenten este issue liestando qué materiales necesitarian.

sebalander, 2025-05-03:
ok, gracias. el lunes lo busco.

no se olviden de los materiales para adherir

lauri-an, 2025-05-06:
Un material para adherir al zircon podría ser poxipol (?
Para cortar el lego dejamos una marca al costado

sebalander, 2025-05-06:
ok. conseguiremos poxipol y algo para cortar el lego.

lauri-an, 2025-05-06:
El panel lego ya esta cortado y ya tenemos el poxipol

Closed 2025-05-06.

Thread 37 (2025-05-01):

Pregunta del grupo OpenMV al grupo de Movilidad

sebalander, 2025-05-01:
En clase me plantearon en el grupo OpenMV que necesitaban consultar algo al grupo de Movilidad. Dejo este issue en blanco para que se estriban entre ustedes y hagan la consulta. Usen este Issue como un chat/hilo de intercambio pero que a la vez sera el registro de como se reolvio el asunto.

grupo **OpenMv**:
 - @3liasCo
 - @rafaelmoya2010
 - @roma1keta

grupo **Movilidad**:
 - @Vale15-tb
 - @mijaelb78
 - @vickyT049

3liasCo, 2025-05-01:
Hola! Queria saber cómo tenía que ser el ángulo que necesitan para que se maneje el robot.
El cuadro azul de la imagen es lo que ve la cámara, nosotros estamos haciendo que calculé en radianes el ángulo que tiene la pelota respecto al eje de la camara, si el ángulo esta a la izquierda del eje va a ser positivo, si está a la derecha del eje va a ser negativo.
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

vickyT049, 2025-05-06:
0 equivale a sentido horario y 1 equivale a sentido antihorario

vickyT049, 2025-05-06:
para poder movernos en grados nosotros usamos regla de tres simple ,osea tomamos un valor como referencia y de ahí cualquier ángulos es multiplicado por el tiempo y dividido por el grado de referencia que elegimos ej:

 #include <Arduino.h>
#include <zirconLib.h>
float angulo;

float girar (float angulo) {

  float tiempo = angulo * 0.075 / 90;

  motor1(100, 1);
  motor2(100, 1);
  motor3(100, 1);
  delay(tiempo);
  motor1(0, 1);
  motor2(0,1);
  motor3(0,1);
  delay(2000);
  return tiempo;
}
void setup(void)
{
  Serial.begin(9600);
  InitializeZircon();

}

void loop(void)
{
 angulo=60;
 Serial.print("el angulo que gira es: " );
 Serial.println(girar(angulo));
}

Closed 2025-05-26.

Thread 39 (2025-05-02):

Tutorial Diseño 3D

Martii3141, 2025-05-02:
# 🧊 Primeros Pasos en Diseño 3D con Tinkercad

Vamos a empezar a explorar el mundo del diseño 3D usando Tinkercad.

Para dar nuestros primeros pasos, mira este video introductorio. Te enseñara lo basico para empezar a moverte en la plataforma:

https://www.youtube.com/watch?v=csvBRWfgf1I&ab_channel=ElRinc%C3%B3ndePrimaria

---

# 🛠️ Actividad: Diseñando un Disco con Agujeros

Ahora que viste el video y exploraste un poco Tinkercad, tu primera mision de diseño es sencilla:

1.  **Crea un disco:** Usa las formas basicas para hacer un cilindro plano que parezca un disco. Que no mida mas de 1 cm de alto.
2.  **Haz dos agujeros:** Usa las formas "huecas" para hacer dos agujeros circulares pequeños en alguna parte de tu disco.
3.  **Agrupa todo:** Asegurate de agrupar el disco y los agujeros para que se conviertan en una sola pieza.

¡Animate a probar las herramientas basicas que viste en el video para lograrlo!

---
@mijaelb78
- [ ] Video
- [ ] Disco con huecos
---
@vickyT049
- [x] Video
- [x] Disco con huecos
---
@rafaelmoya2010
- [x] Video
- [x] Disco con huecos

sebalander, 2025-05-07:
@mijaelb78 cargue el model stl "Smashing Jofo.stl" en el software para procesarlo antes de mandar a la impresora 3D y me lo toma como que tiene 2cm de diamtro el disco:

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

asi que antes de imprimir lo voy a escalear para que tenga 10cm de diametro.

mijaelb78, 2025-05-07:
Hola profe yo lo hice pero no me deja haberlo al que descargue aller,ya lo voy a hacer en mi notebook y se lo mando

Closed 2025-05-30.

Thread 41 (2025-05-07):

Especificación de la Función "MovimientoLineal"

sebalander, 2025-05-07:
## Objetivo

Implementar una función en Arduino para controlar el movimiento lineal del robot en una de las tres direcciones definidas por los ejes de sus tres motores.

## Nombre de la Función

Copiar y pegar esta plantilla de coigo y luego completar el contenido de la funcion.

```cpp
/**
 * @brief Controla el movimiento lineal del robot en la dirección de uno de sus tres ejes.
 *
 * @param eje Número del eje (1, 2 o 3) que define la dirección de movimiento.
 *        - 1: Movimiento en la dirección del primer motor.
 *        - 2: Movimiento en la dirección del segundo motor.
 *        - 3: Movimiento en la dirección del tercer motor.
 *
 * @param distancia Distancia a recorrer en centímetros. Puede ser positiva ("hacia donde apunta" la rueda del eje seleccionado) o negativa (dirección opuesta).
 *
 * @note Factor de conversión entre distancia y tiempo de giro ... ESPECIFICAR ACA XXX
 */
void MovimientoLineal(int eje, float distancia){
  // aca deben completar con su codigo
  // activar motores, delays, etc
}
```

## Comportamiento Esperado

1. Según el valor del parámetro "eje", la función debe definir qué motores activar y en qué sentido.
2. La dirección de giro de cada motor debe depender del signo de "distancia":

   * Distancia positiva: Movimiento en dirección del eje.
   * Distancia negativa: Movimiento en dirección opuesta.
3. Los motores deben activarse durante un tiempo proporcional al valor absoluto de "distancia". Ustedes deben definir el factor de conversión entre distancia (cm) y tiempo (ms) experimentalmente y explicitarlo en su código.

## Recomendaciones

* Utilicen un sistema de funciones auxiliares si lo consideran necesario (por ejemplo, para activar motores con sentido y velocidad específicos).
* Definan el factor de conversión como una constante al inicio del script, de modo que sea fácil de ajustar.
* Comenten adecuadamente el código para explicar su lógica.

sebalander, 2025-05-28:
veo el commit https://github.com/IITA-Proyectos/RoboCupJunior-Soccer-Open-League-2025/commit/d346c5cf93bff2cf32a2fe2d26a9df823abd8848 que ya parece que esta mas cerca de terminarse la tarea, pero falta.

sebalander, 2025-06-04:
[Draft]
@vickyT049 estamos mirando el codigo que subio @Vale15-tb  recien en el commit https://github.com/IITA-Proyectos/RoboCupJunior-Soccer-Open-League-2025/commit/852f60ffdfc7c725dab4cf56046461df535bd3fe. veo por ejemplo esto:

```c
float girar (float tiempo) {

tiempo = angulo * 0.075 / 90;
motor1(100, 1);
motor2(100, 1);
motor3(100, 1);
delay(girar);
motor1(0, 1);
motor2(0, 1);
motor3(0, 1);
delay(2000);

return tiempo;
}
```

trato de entender que quisieron  hacer. les hago algunas preguntas, como para que me expliquen y entender un poco su idea. quiza asi entienda como ayudarlas mejor

1. el input de la funcion `girar` es un tiempo:
```c
float girar (float tiempo) {
```

Martii3141, 2025-06-12:
@vickyT049 la ultima clase estuvimos charlando sobre como hacer las funciones correctamente con sus repectivos argumentos y demas. Pudiste avanzar algo? Seguis teniendo dudas de como hacer algo con ese codigo? Por favor subilo al codigo asi vemos que hiciste, tambien si tenes alguna duda sobre como seguir con el codigo preguntanos asi te ayudamos.

sebalander, 2025-06-25:
@vickyT049 si entendi bien, todavia tenes para trabajar la funcion de giro. trata de avanzar en tu casa asi traes algo ya para testear el martes. si necesitas ayuda avisa.

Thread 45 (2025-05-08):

Mas diseño 3D

Martii3141, 2025-05-08:
# Diseño 3D: Prototipos Iniciales en Tinkercad

Actividades de diseño en Tinkercad para empezar a crear prototipos para nuestro robot.
Cada uno hagan una actividad. Yo les asigne de una manera. Si quieren cambiarse la actividad entre ustedes no hay problema. La idea es que las tres actividades queden hechas, no importa por quien.
---

**Actividad 1: Estructura de 3 Pisos**

Diseñar en Tinkercad una estructura basica que permita ensamblar tres niveles o pisos para el robot. Piensen en como unirian las bases de cada piso.

- [ ] @vickyT049

---

**Actividad 2: Pieza Compatible con Lego**

Diseñar en Tinkercad una pieza que se pueda ensamblar con bloques de Lego. Puede ser una base con orificios o una pieza con espigas que coincidan aproximadamente con las dimensiones de los Legos para poder atornillarla o pegarla a otras partes.

- [ ] @rafaelmoya2010

---

**Actividad 3: Soporte de Camara con Inclinacion**

Diseñar en Tinkercad un soporte para la camara que permita cambiar su angulo de inclinacion. Piensa en un mecanismo sencillo que permita ajustar la posicion de la camara hacia arriba o hacia abajo.

- [ ] @mijaelb78

---

sebalander, 2025-05-30:
primera idea, construir en tinkercad un primer prototipo donde el arco  en realidad no sea curvo, sino que sean mas bien columnas rectas, que arriba se unan con una viga horizontal, que seria la manija.

vickyT049, 2025-06-03:
https://www.tinkercad.com/things/aD3iHP7unZN-estructura-para-los-pisos/edit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
primer diseño de las estructuras

Martii3141, 2025-06-04:
@vickyT049  estamos tratando abrir el link con seba y no nos esta dejando, fijate si nos lo podrias pasar por whatsapp al link porfis asi mandamos a imprimir el stl

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
ese error nos tira cuando abrimos el link

sebalander, 2025-06-04:
@vickyT049 como tarea para el martes que viene seria que avances con mejoras en el diseño 3D. si tenes ideas compartilas por aca y las discutimos. si tenes algun STL donde plasmaste una idea, subilo asi lo puedo abrir yo en 3D y verlo.

Martii3141, 2025-06-12:
@vickyT049 como va el diseño de la estructura? hubo alguna novedad con eso esta semana? Si tenes algun archivo para mandar, pasalo porfis asi lo hacemos imprimir y lo testeamos lo antes posible. Si todavia no hay archivo, me gustaria ver una fotito por lo menos de como va la cosa jaja, me da curiosidad como va quedando esa idea que estaba genial cuando la vi

sebalander, 2025-06-23:
@vickyT049 ... pasanos lo que sea que tengas. dejanos ver tu diseño, asi te podemos ayudar. Lo mejor seria si podes subir el STL a la carpeta de diseño 3D.
el link de tinkercad que pasaste antes lo intente abrir pero me sigue dando error.

sebalander, 2025-06-23:
@mijaelb78 pudiste hacer algo del diseño de soporte de camara que me habias comentado?

mijaelb78, 2025-06-23:
Hola profe si logré hacer una pared más alta para la cámara con orificios para atornillarla y la bace es de 15 cm y lo de la pared sería de 3 cm de altura

sebalander, 2025-06-23:
buenisimo! aca si queres ir investigando las dimensiones de esos agujeros, hay que buscar en la pagina del fabricante de la OpenMV. ahi tienen que tener diagramas detallados de las dimensiones.

fijate aca: https://openmv.io/products/openmv-cam-h7-plus

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

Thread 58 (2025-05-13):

control modo arquero

ASH101-CODE, 2025-05-13:
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

sebalander, 2025-05-16:
@ASH101-CODE avisame como venis, si necesitas algo.

minimamente proba de meter el codigo que tenes en tinckercad y empeza a probarlo. ponele prints para que imprima informacion de lo que esta calculando en el serial monitor asi podes ir entendiendo lo que hace.

ASH101-CODE, 2025-05-20:
// Constantes
const float ANGULO_REFERENCIA = 10.0;      // grados
const float DISTANCIA_REFERENCIA = 50.0;   // cm

// Función que calcula el desplazamiento lateral
float calcularDesplazamiento(float anguloGrados, float distanciaCm) {
  // Convertir ángulo a radianes para usar tan()
  float anguloRad = radians(anguloGrados);

  // Calcular desplazamiento lateral (positivo = derecha, negativo = izquierda)
  float desplazamiento = distanciaCm * tan(anguloRad);

  return desplazamiento; // en centímetros
}

void setup() {
  Serial.begin(9600);
  Serial.println("Modo arquero iniciado.");
}

void loop() {
  // Simulamos inputs de ejemplo (podés reemplazar esto por valores reales)
  float anguloInput = 10.0;      // en grados
  float distanciaInput = 50.0;   // en cm

  // Calcular desplazamiento
  float desplazamientoLateral = calcularDesplazamiento(anguloInput, distanciaInput);

  // Mostrar resultado
  Serial.print("Ángulo: ");
  Serial.print(anguloInput);
  Serial.print("°, Distancia: ");
  Serial.print(distanciaInput);
  Serial.print(" cm → Desplazamiento lateral: ");
  Serial.print(desplazamientoLateral);
  Serial.println(" cm");

  delay(1000); // Esperar 1 segundo antes de repetir
}

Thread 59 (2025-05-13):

para de investigación para el profe

vickyT049, 2025-05-13:
@sebalander buscar como conectar la teensy al Arduino para poder programar

sebalander, 2025-05-16:
@vickyT049  te comento lo que estoy probando en mi compu portatil (creo que es igual que la tuya asi que deberiamos poder lo mismo)

# instalar la IDE de arduino
nada que decir, es facil

# Seguir el instructivo dettensyduino para instalar en la IDE de Arduino la libreria teensyduino

https://www.pjrc.com/teensy/teensyduino.html

# identificar que Tennsy tenemos, fijate en la propia placa:

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aca dice que es teensy 4.1

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este detalle del modelo del chip a veces suele ser util para identificar con mucha precision que teensy tenemos

alternativamente hay otras formas de identificar, hay tutoriales que te hacen contar la cantidad de pines, por ejemplo.

la porpia Ide de Arduino ayuda a veces, por ejemplo aca la detecta y la lista al final del desplegable:

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

# seleccion de la Teensy 4.1

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

# probar algun ejemplo

la IDE trae ejemplos precargados

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

sebalander, 2025-05-22:
resuelto @vickyT049 ? si ya esta, cerra el issue

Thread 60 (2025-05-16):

Transformacion en perspectiva

sebalander, 2025-05-16:
Para estudiar teoria sobre transformacion en perspectiva. la idea es tomar coordenadas pixeles (2D) y calcular con eso coordenadas en cm en el espacio fisica (el plano 2D)

Ver este ejemplo y explicacion:
https://www.youtube.com/watch?v=y1EgAzQLB_o

Esta son las dos funciones que se van a utilizar mas abajo:
- https://docs.opencv.org/3.4/d9/d0c/group__calib3d.html#ga4abc2ece9fab9398f2e560d53c8c9780
- https://docs.opencv.org/3.4/d2/de8/group__core__array.html#gad327659ac03e5fd6894b90025e6900a7

### **Actividad Práctica: Transformación de Perspectiva (Google Colab)**

#### **Materiales:**

* Hoja de papel (A4 o cualquier tamaño conocido).
* Cámara (puede ser la de un celular).
* Cuenta de Google y acceso a Google Colab.

---

#### **1. Preparación del Entorno:**

* Coloca la hoja de papel sobre una superficie plana (mesa o piso).
* Dibuja una cruz en algún lugar dentro de la hoja.

#### **2. Captura de la Imagen:**

* Toma una fotografía de la hoja desde un ángulo inclinado, simulando la vista que tendría la cámara de tu robot (mirando hacia abajo y en ángulo).
* Asegúrate de que en la imagen se vean claramente las cuatro esquinas de la hoja y la cruz dibujada.
* Sube la imagen a Google Colab.

---

#### **3. Configuración de Google Colab:**

* Abre un nuevo notebook en Google Colab.
* Instala y carga las librerías necesarias:

```python
# Instalar OpenCV (si es necesario)
!pip install opencv-python-headless -q

import cv2
import numpy as np
import matplotlib.pyplot as plt
```

---

#### **4. Cargar y Mostrar la Imagen:**

```python
from google.colab import files
from PIL import Image

# Subir la imagen
uploaded = files.upload()
image_path = list(uploaded.keys())[0]

# Cargar la imagen
imagen = cv2.imread(image_path)
imagen_rgb = cv2.cvtColor(imagen, cv2.COLOR_BGR2RGB)

# Mostrar la imagen
plt.imshow(imagen_rgb)
plt.title("Imagen Original")
plt.show()
```

---

#### **5. Identificación de Coordenadas en la Imagen:**

* Identifica a ojo las coordenadas de las cuatro esquinas de la hoja en la imagen (en píxeles).
* Anota estos cuatro pares de coordenadas (u, v).
* Identifica también las coordenadas de la cruz dibujada en la imagen (u, v).

```python
# Coordenadas en la imagen (u, v) - ajustar estos valores a tu imagen
pts_img = np.float32([
    [150, 200],   # Esquina 1
    [500, 180],   # Esquina 2
    [480, 600],   # Esquina 3
    [130, 620]    # Esquina 4
])

# Coordenadas de la cruz en la imagen (u, v)
pts_cruz = np.float32([[320, 400]]).reshape(-1, 1, 2)
```

---

#### **6. Definición de Coordenadas Físicas:**

* Define las coordenadas físicas reales de las esquinas de la hoja.
* Para una hoja A4 (21 cm x 29.7 cm), puedes usar:

```python
# Coordenadas físicas (x, y) en cm
pts_fisicas = np.float32([
    [0, 0],      # Esquina 1
    [21, 0],     # Esquina 2
    [21, 29.7],  # Esquina 3
    [0, 29.7]    # Esquina 4
])
```
cuidado! las esquinas tienen que estar referidas  a las esquinas que se anotaron en pixeles, en el mismo orden se den listar las coordenadas de las esquinas.
---

#### **7. Cálculo de la Matriz de Homografía:**

```python
# Calcular la matriz de homografía
H, _ = cv2.findHomography(pts_img, pts_fisicas)
```

---

#### **8. Transformación de Coordenadas (Cruz):**

```python
# Aplicar la transformación a la cruz
pts_cruz_fisicas = cv2.perspectiveTransform(pts_cruz, H)

print("Coordenadas físicas de la cruz:", pts_cruz_fisicas[0][0])
```

---

#### **9. Visualización de las Coordenadas Físicas:**

```python
# Visualizar las coordenadas físicas de las esquinas y de la cruz
plt.figure()
plt.scatter(*zip(*pts_fisicas), color='blue', label='Esquinas (cm)')
plt.scatter(pts_cruz_fisicas[0][0][0], pts_cruz_fisicas[0][0][1], color='red', label='Cruz (cm)')
plt.title("Coordenadas Físicas Calculadas")
plt.xlabel("X (cm)")
plt.ylabel("Y (cm)")
plt.grid(True, linestyle='--', alpha=0.6)
plt.legend()
plt.show()
```

---

#### **Resultado Esperado:**

* Verás una gráfica mostrando las coordenadas físicas de las esquinas de la hoja (en azul) y la cruz (en rojo).
* El cálculo de las coordenadas de la cruz se habrá realizado automáticamente usando la homografía.

---

¿Te interesa que simplifique la identificación de coordenadas (u,v) pidiéndole al usuario hacer clic directamente en la imagen para capturarlas automáticamente?

3liasCo, 2025-05-17:
https://youtu.be/ITrexC2MA0c?si=b_uKcWzlCcVmAvrd

sebalander, 2025-05-22:
@3liasCo hacer este issue es tu tarea. anda siguiendolo paso por paso. no es facil, no va a salir de una todo junto, pero anda probando y avisame como venis. ok? asi te doy una mano
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
3liasCo, 2025-06-06:
Me falta calibrar la matriz de transformación para el ángulo fijo en el que este la camara y fijarme si funciona y ¿necesitan las coordenadas reales de la pelota? O la distancia en si del robot a la pelota, no en forma de coordenadas, sino como el módulo del vector de esas coordenadas.
Además de eso no sé que otra cosa más tendría que hacer con la open MV

3liasCo, 2025-06-06:
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

Lo escribí medio mal pero espero que se entienda.
También se puede calcular usando razones trigonométricas pero creo que medir el ángulo de la camara es menos preciso que medir su altura.

sebalander, 2025-06-09:
es una buena solucion. ta bueno. con las razones trigonometricas queda bien elegante. la solucion que vos ya mostras ahi:

d = D * (h - r) / h

permite deducir (te lo dejo como ejercicio jeje pero no es obvio) que las coordenadas x,y que queremos se calculan haciendo:

x = X * (h - r) / h
y = Y * (h - r) / h

donde X,Y son las coordenadas mal calculadas proproyectas hasta el plano del suelo, mientras que x,y son las coordenadas que queremos, proyectando hasta el plano del centro de la pelota

sebalander, 2025-06-11:
@3liasCo viendo entonces el comit que hiciste ayer: https://github.com/IITA-Proyectos/RoboCupJunior-Soccer-Open-League-2025/commit/c79d6f0afd905563eb1dea7996f27628bd089a5f
Esta bueno, es un paso importante.

te dejo como tarea:
1. revisar que el calculo de la transformada de perspectiva es coherente con lo que hace OpenCV. es decir, lo que chatgpt nos dio al definir `aplicar_homografia(x, y, H)`  hay que ver que sea coherente con la definicion que tiene OpenCV de lo que es la transfromada de perspectiva proque es de OpenCV de donde sacamos nuestra matriz calibrada. Tenes para estudiar esta documentacion:
  - https://docs.opencv.org/4.11.0/d2/de8/group__core__array.html#gad327659ac03e5fd6894b90025e6900a7
  - https://docs.opencv.org/4.11.0/da/d54/group__imgproc__transform.html#ga20f62aa3235d869c9956436c870893ae
2. sacar del script cosas que ya no hagan falta, que hayan quedado de la forma anterior de calcular la distancia de la pelota, etc.
3. > la cuenta de perspectiva tiene que ir despues de la homografia
   eso mismo, si

3liasCo, 2025-06-24:
https://colab.research.google.com/drive/1c7wPt0nK1N6JG70tcFwKNy3u0pTYOcno?usp=sharing

sebalander, 2025-06-25:
buenisimo el avance de hoy. que crees que te haria falta para ir haciendo para la semana que viene?

3liasCo, 2025-06-25:
> en el mensaje de error que copiaste no dice que linea del programa falla.

Me acuerdo que me marcaba en azul la línea 97 creo o alguna del final después de la línea 96

sebalander, 2025-06-25:
ok!! es una pista importante. o sea seguro que el problema estaen esta linea:

```python
    uart.write(bytearray(packet))            # Enviar por UART
```

proba de pasarle a alguna IA:
1. una frase diciendo que queres entender un error de codigo, bla bla, explicale que queres hacer
2. pegale el codigo entero para que lo vea completo
3. decile cual es el mensaje de error. pegale lo mas textual posible el mensaje de error y la linea del codigo conde creemos que esta el problema.
4. pedile que te explique que es lo que causa el error

avisame si la explicacion que te de la IA se entiende y te ayuda a saber que hacer.

3liasCo, 2025-07-21:
Hola @sebalander quería saber si se podría hacer un espejo omnidireccional como en este video y saber (modificando el programa que ya está hecho) la distancia de la pelota, usando la transformación geométrica que ya estamos usando, y el ángulo de la pelota respecto del eje de la camara

https://youtu.be/JBdiTaK9jbY?si=4rC_CfJzEvEQlEL2

También encontré este video de unos rusos que utilizan un espejo omnidireccional para saber la posición de robot en la cancha aunque no dan muchos detalles

https://youtu.be/om1k866kMfU?si=t2Oe7XyGBtXHBeGW

Fíjate en el minuto 4:22 tiene subtitulos

3liasCo, 2025-07-26:
<!DOCTYPE html>

<html>

<body>

distancia en pixeles al centro | distancia en centimetros al centro
-- | --
24.0| 25
43.0| 50
66.0| 75
93.0| 100
118.0| 125
139.0| 150
156.0| 175
170.0| 200
182.0| 225
192.0| 250
201.0| 275
208.0| 300
31.11269837220809| 25√2
62.22539674441618| 50√2
98.99494936611666| 75√2
131.52186130069785| 100√2
156.97770542341354| 125√2
175.36248173426378| 150√2
190.91883092036784| 175√2
202.2325394193526| 200√2
212.13203435596427| 225√2

</body>

</html>

sebalander, 2025-07-29:
[funcion de la camara omnidireccional.ggb.zip](https://github.com/user-attachments/files/21497597/funcion.de.la.camara.omnidireccional.ggb.zip)

descomprimilo y adentro esta el .ggb de geogebra tal como me lo pasate

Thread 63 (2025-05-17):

Comuniacion UART Arduino

Martii3141, 2025-05-17:
@Aczino593 te paso una documentacion que nos armo otro profe de como hicieron algunos chicos para poder tener una comunicacion entre la openMV y la Teensy. La propuesta es que vayas leyendo un poco, mas que nada en como recibe los datos la teensy, que es la placa que tiene la base movil que estaban soldando.
- Aca el link: https://github.com/IITA-Proyectos/WRO-SPORT-2025/issues/1#issuecomment-2887187106
Cualquier duda que tengas o si queres mas informacion, avisa asi te pasamos.

Aczino593, 2025-05-18:
Buenas profe pude hacer un código para que el maestro le envié un mensaje al esclavo. Pero como solo tengo una sola placa Arduino, la comunicación se realiza en una sola placa y no en 2.

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

sebalander, 2025-05-19:
@Aczino593 esta buenisimo si ya lo estas probando! esto es I2C? como hablas de maestro y esclavo pensamos que seria I2C. por lo que estuve leyendo UART tendria algunas ventajas respecto a I2C, por eso pregunto.

Aczino593, 2025-05-20:
@rafaelmoya2010 Fíjate la documentación que esta arriba sobre la comunicación OpenMV y teensy

sebalander, 2025-05-22:
# 📡 Protocolo de Comunicación UART: Envío de Pares `TAG–VALOR`

## 📜 Especificación Técnica del Protocolo

Se envían/reciben una secuencia ininterrumpida de bytes, uno atrás del otro sin parar.
Este protocolo especifica cómo interpretarlos:

- El primer byte del par es un **TAG** (identifica qué dato se envía).
- El segundo byte del par es un **VALOR** (codifica un número entre 0 y 200).
- Siempre después de un byte de **TAG**, el que sigue debe ser sí o sí un byte de **VALOR**.

El mensaje consiste en una secuencia de pares `TAG–VALOR`.
Puede tener cualquier cantidad de pares.

Ejemplo:
```
..., 201, 80, 202, 120, 203, 50, ...
```

---

### 🧾 Tabla de Rangos

| Byte  | Rango   | Significado                                  |
|-------|---------|----------------------------------------------|
| TAG   | 201–255 | Identifica el tipo de dato enviado           |
| VALOR | 0–200   | Información numérica asociada al tag previo |

---

### 🔖 Tabla de TAGs

| TAG | Nombre                        | Valor esperado | Conversión al valor real     | Descripción                                                  |
|-----|-------------------------------|----------------|-------------------------------|--------------------------------------------------------------|
| 201 | Pelota – coordenada X        | 0–200          | `x = v / 2`                   | Posición hacia el frente del robot (0–100 cm)               |
| 202 | Pelota – coordenada Y        | 0–200          | `y = v / 2 - 50`              | Posición izquierda/derecha (–50 a 50 cm)                    |
| 203 | Arco enemigo – coordenada X  | 0–200          | `x = v / 2`                   | Posición hacia el frente del robot (0–100 cm)               |
| 204 | Arco enemigo – coordenada Y  | 0–200          | `y = v / 2 - 50`              | Posición izquierda/derecha (–50 a 50 cm)                    |
| 205 | Arco propio – coordenada X   | 0–200          | `x = v / 2`                   | Posición hacia el frente del robot (0–100 cm)               |
| 206 | Arco propio – coordenada Y   | 0–200          | `y = v / 2 - 50`              | Posición izquierda/derecha (–50 a 50 cm)                    |

---

## 🧠 Ejemplo Interpretado

Mensaje recibido:
```
..., 201, 80, 202, 120, 203, 50, ...
```

Se interpreta como:

- TAG 201 → valor 80 → pelota en eje X → `x = 80 / 2 = 40 cm`
- TAG 202 → valor 120 → pelota en eje Y → `y = 120 / 2 - 50 = 10 cm`
- TAG 203 → valor 50 → arco enemigo en eje X → `x = 50 / 2 = 25 cm`

sebalander, 2025-05-22:
@Aczino593 fijate la especificaicon que acabo de poner arriba, anda implementandola para la teensy.

rafaelmoya2010, 2025-05-28:
Hoy lei la comunicación uart y empecé a crear el código para trasladar de open mv a teensy

sebalander, 2025-05-28:
buenisimo, trata de armar un borrador de ese codigo para el martes y traerlo para testearlo directamente.

armalo como tarea para la casa y *pegalo en este issue* asi lo podemos ver antes del martes

rafaelmoya2010, 2025-06-03:
hoy en clases Aczino593 y yo probamos el código que hizo Aczino593 de micropython y teensy, nos daba los valores, pero los valores no cambiaban. Ósea que la OpenMV no mandaba los datos para que la Teensy los reciba. Posiblemente se deba a la conexión que hicimos, porque nos faltaron 2 cables.

Aczino593, 2025-06-10:
Código OpenMV
from pyb import UART
import time

uart = UART(3, 115200) #baudios 115200

# Variables simuladas (fake data)
x_map = 0        # Centro X mapeado (0 a 100)
ang = 0          # Ángulo mapeado (0 a 180)
sentido = 0      # Sentido (0: SV, 1: VI, 2: VD, 3: DV)

while True:
    # Actualizar valores de prueba
    x_map = (x_map + 10) % 101
    ang = (ang + 30) % 181
    sentido = (sentido + 1) % 4

    packet = [
        255, x_map,       # Marca de x_map
        254, ang,         # Marca de ang
        253, sentido      # Marca de sentido
    ]

    print("Enviando paquete:", packet)       # Mostrar qué se envía
    uart.write(bytearray(packet))            # Enviar por UART

    time.sleep_ms(500)  # Esperar medio segundo entre envíos

rafaelmoya2010, 2025-06-10:
en la clase de hoy yo y @Aczino593 logramos hacer la transferencia de datos de micropyton a teency con valores falsos
la próxima clase intentaremos hacer la transferencia con datos verdaderos

sebalander, 2025-07-04:
buenisimo! gran avance.

@Aczino593 @3liasCo @rafaelmoya2010 me imagino que la clase que viene vamos a poder empezar a ver funcionando completo el sistema de vision. o sea me imagino algo como:

1. tener bien instalada la camara en el robot (con legos seguramente)
2. poner el robot en el origen de coordenadas de un sistema de coordenadas x,y en la mesa
3. poner a mano la pelota en alguna posicion x,y que podamos medir en cm
4. la camara deberia detectar la pelota, calcular las coordenadas, codificarlas, y mandar los bytes a la teensy
5. la teensy recibe los bytes, los decodifica y muestra por monitor serie las coordenadas  x,y de la pelota

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

en resumen la idea es que el sistema empiece a funcionar cada vez mas completo. 💪

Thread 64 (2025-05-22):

Dimensiones Cancha

Martii3141, 2025-05-22:
@ASH101-CODE como el otro dia me preguntaste sobre las medidas de la cancha, me parecio buena idea que lo investigues en las reglas de la competicion.
Te paso el link de la pagina de las reglas. Cuando tengas las medidas y especificaciones de toda la cancha, dejalas en el comentario de este issue asi quedan guardadas ya en algun lugar.
https://robocup-junior.github.io/soccer-rules/2025-soccer-draft-rules/rules.html#general-rules --> Link de las reglas

ASH101-CODE, 2025-05-26:
Longitud: 12 metros
Ancho: 8 metros

Closed 2025-05-26.

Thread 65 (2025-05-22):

Integracion del codigo Arquero/Parseo

Martii3141, 2025-05-22:
@ASH101-CODE vamos a necesitar que le pases el codigo a @Leandro284-AR
La idea es que vos Ayelen le expliques el codigo de la logica del arquero a Leandro, para que el pueda integrar ese codigo con el codigo de lorenz. Si podes por favor pasarlo primero al codigo asi le explico mejor a lean como va a hacer esa integracion.

Leandro284-AR, 2025-05-27:
// Constantes
const float ANGULO_REFERENCIA = 10.0; // grados
const float DISTANCIA_REFERENCIA = 50.0; // cm

// Función que calcula el desplazamiento lateral
float calcularDesplazamiento(float anguloGrados, float distanciaCm) {
// Convertir ángulo a radianes para usar tan()
float anguloRad = radians(anguloGrados);

// Calcular desplazamiento lateral (positivo = derecha, negativo = izquierda)
float desplazamiento = distanciaCm * tan(anguloRad);

return desplazamiento; // en centímetros
}

void setup() {
Serial.begin(9600);
Serial.println("Modo arquero iniciado.");
}

void loop() {
// Simulamos inputs de ejemplo (podés reemplazar esto por valores reales)
float anguloInput = 10.0; // en grados
float distanciaInput = 50.0; // en cm

// Calcular desplazamiento
float desplazamientoLateral = calcularDesplazamiento(anguloInput, distanciaInput);

// Mostrar resultado
Serial.print("Ángulo: ");
Serial.print(anguloInput);
Serial.print("°, Distancia: ");
Serial.print(distanciaInput);
Serial.print(" cm → Desplazamiento lateral: ");
Serial.print(desplazamientoLateral);
Serial.println(" cm");

delay(1000); // Esperar 1 segundo antes de repetir
}

Closed 2025-05-27.

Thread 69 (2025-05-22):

Documentacion Giroscopo

sebalander, 2025-05-22:
https://learn.adafruit.com/adafruit-bno055-absolute-orientation-sensor/arduino-code

Dfrobot.com

@mijaelb78 dejo este issue para que vayas documentando la investigacion del giroscopo.

sebalander, 2025-05-22:
si paorta algo, aca hay una demo en tinkercad de giroscopo, la podes testear en tu casa como para ir entendiendola ya que se simula en tinkercad

https://www.tinkercad.com/things/hVvIMdtVEnj-giroscopio

mijaelb78, 2025-06-03:
#include <Wire.h>
#include <Adafruit_Sensor.h>
#include <Adafruit_BNO055.h>
#include <utility/imumaths.h>

/* This driver uses the Adafruit unified sensor library (Adafruit_Sensor),
   which provides a common 'type' for sensor data and some helper functions.

   To use this driver you will also need to download the Adafruit_Sensor
   library and include it in your libraries folder.

   You should also assign a unique ID to this sensor for use with
   the Adafruit Sensor API so that you can identify this particular
   sensor in any data logs, etc.  To assign a unique ID, simply
   provide an appropriate value in the constructor below (12345
   is used by default in this example).

   Connections
   ===========
   Connect SCL to analog 5
   Connect SDA to analog 4
   Connect VDD to 3.3-5V DC
   Connect GROUND to common ground

   History
   =======
   2015/MAR/03  - First release (KTOWN)
*/

/* Set the delay between fresh samples */
#define BNO055_SAMPLERATE_DELAY_MS (100)

// Check I2C device address and correct line below (by default address is 0x29 or 0x28)
//                                   id, address
Adafruit_BNO055 bno = Adafruit_BNO055(55, 0x28);

/**************************************************************************/
/*
    Displays some basic information on this sensor from the unified
    sensor API sensor_t type (see Adafruit_Sensor for more information)
*/
/**************************************************************************/
void displaySensorDetails(void)
{
  sensor_t sensor;
  bno.getSensor(&sensor);
  Serial.println("------------------------------------");
  Serial.print  ("Sensor:       "); Serial.println(sensor.name);
  Serial.print  ("Driver Ver:   "); Serial.println(sensor.version);
  Serial.print  ("Unique ID:    "); Serial.println(sensor.sensor_id);
  Serial.print  ("Max Value:    "); Serial.print(sensor.max_value); Serial.println(" xxx");
  Serial.print  ("Min Value:    "); Serial.print(sensor.min_value); Serial.println(" xxx");
  Serial.print  ("Resolution:   "); Serial.print(sensor.resolution); Serial.println(" xxx");
  Serial.println("------------------------------------");
  Serial.println("");
  delay(500);
}

/**************************************************************************/
/*
    Arduino setup function (automatically called at startup)
*/
/**************************************************************************/
void setup(void)
{
  Serial.begin(115200);
  Serial.println("Orientation Sensor Test"); Serial.println("");

  /* Initialise the sensor */
  if(!bno.begin())
  {
    /* There was a problem detecting the BNO055 ... check your connections */
    Serial.print("Ooops, no BNO055 detected ... Check your wiring or I2C ADDR!");
    while(1);
  }

  delay(1000);

  /* Use external crystal for better accuracy */
  bno.setExtCrystalUse(true);

  /* Display some basic information on this sensor */
  displaySensorDetails();
}

/**************************************************************************/
/*
    Arduino loop function, called once 'setup' is complete (your own code
    should go here)
*/
/**************************************************************************/
void loop(void)
{
  /* Get a new sensor event */
  sensors_event_t event;
  bno.getEvent(&event);

  /* Board layout:
         +----------+
         |         *| RST   PITCH  ROLL  HEADING
     ADR |*        *| SCL
     INT |*        *| SDA     ^            /->
     PS1 |*        *| GND     |            |
     PS0 |*        *| 3VO     Y    Z-->    \-X
         |         *| VIN
         +----------+
  */

  /* The processing sketch expects data as roll, pitch, heading */
  Serial.print(F("Orientation: "));
  Serial.print((float)event.orientation.x);
  Serial.print(F(" "));
  Serial.print((float)event.orientation.y);
  Serial.print(F(" "));
  Serial.print((float)event.orientation.z);
  Serial.println(F(""));

  /* Also send calibration data for each sensor. */
  uint8_t sys, gyro, accel, mag = 0;
  bno.getCalibration(&sys, &gyro, &accel, &mag);
  Serial.print(F("Calibration: "));
  Serial.print(sys, DEC);
  Serial.print(F(" "));
  Serial.print(gyro, DEC);
  Serial.print(F(" "));
  Serial.print(accel, DEC);
  Serial.print(F(" "));
  Serial.println(mag, DEC);

  delay(BNO055_SAMPLERATE_DELAY_MS);
}

mijaelb78, 2025-06-03:
profe eso es con lo que logre avanzar hoy.Para el giroscopo

sebalander, 2025-06-06:
buenisimo @mijaelb78 . te dejo como tarea par antes del martes:

leer la documentacion del giroscopo o investigar como quieras: queremos preservar solo el dato de orientacion, no necesitamos todo lo demas. asi que tenes que ir pensando que partes del codigo se podrian sacar para dejarlo mas limpio y obetener solo el dato que queremos.

otra cosa es saber como se inicializa el giroscopo. hay que saber si cuando se enciende hay que hacer algo especial para que despues el dato de la orientacion sea correcto. ¿se entiende?

el martes, como actividad presencial lo que tendrias que hacer es eso: dejar acomodado un codigo limpio tal que con las minimas lineas de codigo se pueda obtener la orientacion del giroscopo

Closed 2025-08-05.

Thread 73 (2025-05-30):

Calibracion de tiempo para movimiento lineal

sebalander, 2025-05-30:
@Vale15-tb en este issue por favor subi los datos que hayas tomado de la calibracion que estas haciendo para el movimiento lineal. o por lo menos hace una descripcion de lo que estas haciendo (como para documentar). por ejemplo, podes subir a este issue alguna foto del experimento explicando como se tiene que mover el robot y explicando que es lo que vas a medir.

en algun momento como resultado de las mediciones vas a obtener alguna tablita de datos tipo

| delay (mili segundos) | distancia recorrida (cm) |
|-----------------------|--------------------------|
| 500                   | ...                      |
| 600                   | ...                      |
| ...                   | ...                      |

o algo asi.

Vale15-tb, 2025-06-17:
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

sebalander, 2025-06-23:
@Vale15-tb estos datos que tenes en papel: pasalos en digital a una planilla de calculo.

Vale15-tb, 2025-06-24:
Tiempo (s)	Distancia (cm)
125	            7.60
200	            12
250	            15.5
500	            30.5
1000	    59.7

Vale15-tb, 2025-06-25:
https://amyd.quimica.unam.mx/pluginfile.php/6119/mod_resource/content/2/4_TutorialRegresinLineal.pdf

Vale15-tb, 2025-07-01:
[

[RegresionLineal...2.0.xlsx](https://github.com/user-attachments/files/21008335/RegresionLineal.2.0.xlsx)

](url)

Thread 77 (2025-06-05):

Soporte para el servo

Martii3141, 2025-06-05:
@roma1keta estabamos pensando con Seba que en algún momento vamos a necesitar que de algún modo el Servomotor se adapte a todo el resto de cosas. Googleando dimos con una pagina que tiene muchos modelos que pueden llegar a servir por ahora.
La propuesta es que elijas el modelo que quieras de la pagina que te voy a pasar, descargues el archivo del modelo y nos lo pases al archivo que termina en .STL, asi lo mandamos a imprimir. Vos elegí el que mas te guste, no hay problema.
Link de la pagina --> https://m.yeggi.com/q/servo+bracket/
Por otro lado, por si queres buscar de mas lugares o queres ver otros modelos, yo googlee "Servomotor bracket 3D" y fue el mejor resultado que obtuve, si queres probar vos googleando con esas palabras clave y buscar de otro lado tampoco hay problema.
Avisanos cualquier cosa

Closed 2025-06-17.

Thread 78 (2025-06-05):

Soporte para Motor amarillo

Martii3141, 2025-06-05:
@xio02 te propongo que busques de la pagina que te voy a dejar mas abajo, algún modelo que nos sirva de momento, para poder instalar de forma mas efectiva el motor amarillo, en todo el sistema. La idea es que vos elijas el que mas te convenza, descargues el archivo del modelo y nos pases el que termina en .STL, asi lo mandamos a imprimir.
Link de la pagina --> https://m.yeggi.com/q/yellow+motor+mount/
Tambien si querés buscar modelos que no sean de la pagina, podes googlear "yellow gearbox motor bracket" y por lo menos a mi fue la busqueda que mejores resultados me dió. Avisa cualquier cosa.

lauri-an, 2025-06-25:
Como?

lauri-an, 2025-06-25:
Ya vi uno pero no se como descargarlo

sebalander, 2025-07-23:
@Martii3141 te pido si podes imprimir a modo de testeo (en el slicer filling al 10% y espesor de corteza de 0.4mm, o lo que sea para que se imprima rapido no mas) de esta pieza de testeo.

https://github.com/IITA-Proyectos/RoboCupJunior-Soccer-Open-League-2025/blob/main/Dise%C3%B1o3D/soporte%20TT%20motor_recortado%202025-07-23%20-%20seba.stl

es para verificar que los orificios estan bien posicionadios. si es asi despues se puede mandar la pieza completa

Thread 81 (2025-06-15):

Rango parametrosLorentz

Martii3141, 2025-06-15:
@Leandro284-AR necesitamos que trates de ver alguno de los tres parametros que devuelve el codigo del generador de lorentz (alguno de los parametros que se envian por RX/TX) y que veas en que rango masomenos se encuentran los valores que arroja. Esto lo vamos a necesitar ya que ayelen tiene el codigo nuevo del arquero con una funcion que depende de la distancia que tiene la pelota con respecto al arco, y si esa distancia es menor a algun numero (el valor de alguno de los parametros de lorentz) que entonces despeje la pelota. La idea es empezar a hacer pruebas mas motoras con eso, entonces necesitamos pinchar de algun lado por ahora la distancia y para eso lo unico que tenemos es el Generador. Te animas a ver en que rango se encuentra alguno de los parametros que arroja el codigo y despues dejarlo escrito por aca asi lo tenemos para ayelen?

Martii3141, 2025-06-20:
@Leandro284-AR avisame si es que tenes alguna duda con respecto a algo de este issue

Closed 2025-07-08.

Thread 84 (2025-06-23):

Diseño 3D para soporte del Dribbler

sebalander, 2025-06-23:
@xio02 este issue es para que hagamos un seguimiento de tu diseño 3D para el soporte del dribbler.

La idea es que pruebes diseñar lo que seria el lugar donde se agarria el dribbler. en este momento viste que estamos usando el panle amarillo de lego. bueno, empeza por hacer un reemplazo de eso.

hace una cuenta de tinkercad y diseña ahi un disco de 2mm de grosor y del mismo diametro que el robot. se entiende?

sebalander, 2025-07-10:
@xio02 cierro este issue. si queres hacer diseño 3D lo reabrimos

Closed 2025-07-10.

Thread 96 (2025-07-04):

estimador de posicion (filtro kalman?)

sebalander, 2025-07-04:
## Estimador de Posición del Robot

@Aczino593 te dejo este issue para que vayamos discutiendo cómo hacer este estimador.

### Objetivo

Queremos que el robot tenga un algoritmo corriendo en la **Teensy** que mantenga las variables `(x, y, θ)` representando su posición en la cancha.

Pero:
🚨 *La posición del robot cambia constantemente*, así que necesitamos una forma de **actualizar (x, y, θ)** en tiempo real, de forma que estas variables estén lo más cercanas posible a la **posición real** del robot.

---

### Fuentes de información disponibles

El robot, como parte de su funcionamiento, va a:

- 🔭 Ver los **arcos de la cancha**
- 🧭 Leer la **orientación de la brújula**
- 🛞 Enviar **comandos de movilidad a las ruedas**
- ❓ ¿Alguna otra variable relacionada con la posición que se te ocurra a vos?

---

### Algunas ideas obvias

- 📍 Si conozco la **posición de los arcos**, y detecto un arco en una cierta posición respecto a mí mismo → puedo **inferir mi propia posición**
- 🧭 La **orientación de la brújula** debería ser una medición directa y confiable de la orientación del robot → esta es fácil
- ↔️ Si le mando a las ruedas que se desplacen 10 cm → puedo predecir que me he desplazado aproximadamente esa distancia

---

### Problema

Cada método tiene **errores**.
Si usamos dos métodos, **no van a dar exactamente lo mismo**.
Entonces:
➡️ ¿Cómo podemos combinar múltiples fuentes de información de forma coherente?

---

### que vamos a hacer

Abrimos este issue para empezar a **armar una estrategia** de cómo juntar toda esa información mediante **algún cálculo (estimador)**.

Primero:  ¿Se entiende este planteo? ¿Entendés cuál es el problema que queremos resolver?

---

### material para estudiar

Leé:
📖 https://www.kalmanfilter.net/ES/default_es.aspx → Solo la parte de **"Mirada general"**

Despues de eso lo que sigue es:
- Parte 1. Introducción al filtro Kalman: cuyas secciones son:
    - Revisión de conceptos  https://www.kalmanfilter.net/ES/background_es.html
    - El filtro α−β−γ  https://www.kalmanfilter.net/ES/alphabeta_es.html
    - Filtro de Kalman en una dimensión https://www.kalmanfilter.net/ES/kalman1d_es.html

Pero tranqui, no lo leas todo de una.
⏳ Empezá solo con **"Mirada General"**, y si te parece fácil, seguí con **"Revisión de conceptos"**.

sebalander, 2025-07-04:
dejo por aa otra referencia con graficas lindas, pero que me parece demasiado avanzada https://www.bzarg.com/p/how-a-kalman-filter-works-in-pictures/

sebalander, 2025-07-10:
@Aczino593 hasta donde pudiste leer? si terminas de leer avisame y charlamos como seguir

sebalander, 2025-07-24:
@Aczino593 algun update?

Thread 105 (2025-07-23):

subir STL de soporte de camara para imprimir

sebalander, 2025-07-23:
hacer las modificaciones que me exlpicaste en clase del modelo Fabulous Lappi.stl.

subir el STL y contestame en este issue con el link el archivo STL asi lo puedo descargar y lo mando a imprimir

mijaelb78, 2025-08-05:
profe me podria  imprimir lo ultimo que subi para la base de la camara de nomre le puse "base para la camara ultimo modelo"
https://github.com/IITA-Proyectos/RoboCupJunior-Soccer-Open-League-2025/commit/620f9f96657772f26cacef9e4d490f532b75e9dc
ese es el link

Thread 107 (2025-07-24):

Movimiento con Giroscopo

Martii3141, 2025-07-24:
@Vale15-tb te dejo aca un codigo que indica las cosas que si o si van a tener que estar en el codigo que va a manejar el giroscopo. Y tambien una forma sencilla para que termines de completar vos la logica del codigo ya midiendo el angulo de movimiento en el eje Z y de esa forma el robot se pueda mvoer un angulo dado.
```cpp // --- 1. LIBRERIAS (¡ESTO ES OBLIGATORIO!) ---
#include <Wire.h>          // Para que Arduino hable con el sensor (comunicacion I2C).
#include <Adafruit_Sensor.h> // Una libreria base para sensores de Adafruit.
#include <Adafruit_BNO055.h> // La libreria especifica para tu sensor BNO055.
#include <utility/imumaths.h> // Ayuda con las matematicas internas del sensor.

// --- 2. EL SENSOR EN TU CODIGO (¡ESTO ES OBLIGATORIO!) ---
// Creamos un "objeto" llamado 'bno' para poder darle ordenes al sensor.
// El numero '55' es solo un identificador.
Adafruit_BNO055 bno = Adafruit_BNO055(55);

void setup(void) {
  // --- 3. PREPARAR EL MONITOR SERIE (¡ESTO ES OBLIGATORIO para ver los datos!) ---
  Serial.begin(9600);
  Serial.println("--- Iniciando Sensor de Giro (BNO055) ---");
  Serial.println("Mueve el sensor para que se calibre y veras los angulos.");
  Serial.println("------------------------------------------");

  // --- 4. INICIAR EL SENSOR (¡ESTO ES OBLIGATORIO!) ---
  // Le decimos al sensor que "despierte" y empiece a funcionar.
  // Si algo sale mal (por ejemplo, los cables estan flojos), te avisara.
  if (!bno.begin()) {
    Serial.println("¡Ups! No encontre el sensor BNO055. Revisa tus cables.");
    while (1); // Si no lo encuentra, el programa se detiene aqui.
  }

  delay(1000); // Esperamos un segundo para que el sensor este listo.

  Serial.println("Sensor listo. ¡A girar!");
  Serial.println("------------------------------------------");
}

void loop(void) {
  // --- 5. LEER LOS DATOS DEL SENSOR (¡ESTO ES OBLIGATORIO en cada vuelta del loop!) ---
  // Creamos un "paquete de datos" (lo llamamos 'datosSensor')
  sensors_event_t datosSensor;
  // Y le pedimos al sensor que llene ese paquete con la informacion mas reciente.
  bno.getEvent(&datosSensor);

  // --- ¡AQUI ESTA EL ANGULO QUE NECESITAS! ---
  // El angulo de giro en el eje Z (Heading/Yaw) es el que te dice hacia donde mira tu robot.
  // Es como la lectura de una brujula.
  float anguloDeGiroEjeZ = datosSensor.orientation.x;

  // --- AQUI ES DONDE USARAS 'anguloDeGiroEjeZ' ---
  // Por ejemplo, para hacer que tu robot gire a un angulo especifico:
  // if (anguloDeGiroEjeZ > 90) {
  //   // Mueve el motor para girar a la izquierda
  // } else if (anguloDeGiroEjeZ < 90) {
  //   // Mueve el motor para girar a la derecha
  // } else {
  //   // Deten el motor, ¡llegaste al angulo!
  // }

  // --- MOSTRAR EL ANGULO EN LA PANTALLA (Monitor Serie) ---
  Serial.print("Angulo de Giro (Eje Z): ");
  Serial.print(anguloDeGiroEjeZ, 2); // Muestra el numero con 2 decimales
  Serial.println(" grados"); // Agrega " grados" y salta a la siguiente linea

  delay(100); // Una pequeña pausa para no llenar la pantalla de numeros muy rapido.
}```

La idea es que trates de completar la logica del movimiento de los motores que irian dentro de los if. Anda completando esto en tu casa, asi cuando llegues el martes que viene al IITA lo probas de una y vamos modificando sobre eso que ya tenes escrito y pensado. Si tenes alguna duda avisa y te damos una mano

Martii3141, 2025-07-31:
@Vale15-tb subi por favor el codigo que hiciste ya sea aca o como codigo en la carpeta de movilidad asi vemos que hiciste

Vale15-tb, 2025-08-19:
#include <Arduino.h>
#include <zirconLib.h>
#include <Wire.h>          // Para que Arduino hable con el sensor (comunicacion I2C).
#include <Adafruit_Sensor.h> // Una libreria base para sensores de Adafruit.
#include <Adafruit_BNO055.h> // La libreria especifica para tu sensor BNO055.
#include <utility/imumaths.h> // Ayuda con las matematicas internas del sensor.

// --- 2. EL SENSOR EN TU CODIGO (¡ESTO ES OBLIGATORIO!) ---
// Creamos un "objeto" llamado 'bno' para poder darle ordenes al sensor.
// El numero '55' es solo un identificador.
Adafruit_BNO055 bno = Adafruit_BNO055(55);

unsigned long tiempoAnterior = 0;
const long intervalo = 1000; // 1 segundo

void setup(void) {
  InitializeZircon();
  // --- 3. PREPARAR EL MONITOR SERIE (¡ESTO ES OBLIGATORIO para ver los datos!) ---
  Serial.begin(9600);
  Serial.println("--- Iniciando Sensor de Giro (BNO055) ---");
  Serial.println("Mueve el sensor para que se calibre y veras los angulos.");
  Serial.println("------------------------------------------");

  // --- 4. INICIAR EL SENSOR (¡ESTO ES OBLIGATORIO!) ---
  // Le decimos al sensor que "despierte" y empiece a funcionar.
  // Si algo sale mal (por ejemplo, los cables estan flojos), te avisara.
  if (!bno.begin()) {
    Serial.println("¡Ups! No encontre el sensor BNO055. Revisa tus cables.");
    while (1); // Si no lo encuentra, el programa se detiene aqui.
  }

  delay(1000); // Esperamos un segundo para que el sensor este listo.

  Serial.println("Sensor listo. ¡A girar!");
  Serial.println("------------------------------------------");
}

void loop(void) {
  // --- 5. LEER LOS DATOS DEL SENSOR (¡ESTO ES OBLIGATORIO en cada vuelta del loop!) ---
  // Creamos un "paquete de datos" (lo llamamos 'datosSensor')
  sensors_event_t datosSensor;
  // Y le pedimos al sensor que llene ese paquete con la informacion mas reciente.
  bno.getEvent(&datosSensor);

  // --- ¡AQUI ESTA EL ANGULO QUE NECESITAS! ---
  // El angulo de giro en el eje Z (Heading/Yaw) es el que te dice hacia donde mira tu robot.
  // Es como la lectura de una brujula.
  float anguloDeGiroEjeZ = datosSensor.orientation.x;

  // --- AQUI ES DONDE USARAS 'anguloDeGiroEjeZ' ---
  // Por ejemplo, para hacer que tu robot gire a un angulo especifico:

      unsigned long tiempoActual = millis();
if (tiempoActual - tiempoAnterior >= intervalo) {
  Serial.print("tiempoActual ");
        tiempoAnterior = tiempoActual;
  Serial.print("tiempoActual ");
}

   if (anguloDeGiroEjeZ > 90) {
    Serial.print("a la derecha ");

    motor1(anguloDeGiroEjeZ,0);
    motor2(anguloDeGiroEjeZ,0);
    motor3(anguloDeGiroEjeZ,0);
    delay(1000);

 }else{
   Serial.print(" a la izquierda");
    motor1(anguloDeGiroEjeZ,1);
    motor2(anguloDeGiroEjeZ,1);
    motor3(anguloDeGiroEjeZ,1);
    delay(1000);

   }

  //   // Mueve el motor para girar a la derecha
  // } else {
      //   motor1(0,1)
      //   motor2(0,1)
      //   motor3(0,1)
  //   // Deten el motor, ¡llegaste al angulo!
  // }

  // --- MOSTRAR EL ANGULO EN LA PANTALLA (Monitor Serie) ---
  Serial.print("Angulo de Giro (Eje Z): ");
  delay(1000);
  Serial.print(anguloDeGiroEjeZ, 2); // Muestra el numero con 2 decimales
  delay(1000);
  Serial.println(" grados"); // Agrega " grados" y salta a la siguiente linea

  delay(100); // Una pequeña pausa para no llenar la pantalla de numeros muy rapido.
}

Vale15-tb, 2025-10-04:
angulo sería igual a
flotat angulo= anguloDeGiroEjeZ
Puede ser un número con coma

Vale15-tb, 2025-10-05:
int minVal=265; // Valor mínimo esperado de la lectura analógica
int maxVal=402; // Valor máximo esperado de la lectura analógica
double x, y, z; // Variables para almacenar ángulos calculados

void setup()
{
  pinMode(2, OUTPUT);   // Pin 2 configurado como salida (LED)
  pinMode(3, OUTPUT);   // Pin 3 configurado como salida (LED)
  pinMode(4, OUTPUT);   // Pin 4 configurado como salida (LED)
  Serial.begin(9600);   // Inicia comunicación serial a 9600 baudios
}

void loop()
{
  int vx = analogRead(A0);  // Lee valor analógico del pin A0
  int vy = analogRead(A1);  // Lee valor analógico del pin A1
  int vz = analogRead(A2);  // Lee valor analógico del pin A2

  // Mapea valores de lectura a un rango de -90 a 90 grados
  int xAng = map(vx, minVal, maxVal, -90, 90);
  int yAng = map(vy, minVal, maxVal, -90, 90);
  int zAng = map(vz, minVal, maxVal, -90, 90);

  // Calcula ángulos en grados usando funciones trigonométricas
  x = RAD_TO_DEG * (atan2(-yAng, -zAng) + PI);
  y = RAD_TO_DEG * (atan2(-xAng, -zAng) + PI);
  z = RAD_TO_DEG * (atan2(-yAng, -xAng) + PI);

  // Imprime valores de los ángulos en el monitor serial
  Serial.print("X: ");
  Serial.println(x);
  Serial.print("Y: ");
  Serial.println(y);
  Serial.print("Z: ");
  Serial.println(z);
  Serial.println("--------");

  delay(3000);  // Espera 3 segundos para la próxima lectura

  // Condicionales para encender LEDs si la lectura supera 5
  if (vx > 5) {
    digitalWrite(2, HIGH);  // Enciende LED en pin 2
    delay(3500);            // Mantiene encendido por 3.5 segundos
    digitalWrite(2, LOW);   // Apaga LED en pin 2
  }
  if (vy > 5) {
    digitalWrite(3, HIGH);  // Enciende LED en pin 3
    delay(3500);
    digitalWrite(3, LOW);
  }
  if (vz > 5) {
    digitalWrite(4, HIGH);  // Enciende LED en pin 4
    delay(3500);
    digitalWrite(4, LOW);
  }
}

Vale15-tb, 2025-10-05:
//código para probar si la función millis funciona....probar primero
# include <Arduino.h>
#include <zirconLib.h>
angulo=60
tienpoAnterior=angulo
void setup(void)
{

  InitializeZircon();

}

void loop(void)
{

unsigned long tiempoActual = millis();
if (tiempoActual - tiempoAnterior >= intervalo) {
Serial.print("tiempoActual ");
tiempoAnterior = tiempoActual;
Serial.print("tiempoActual ");
}
if (anguloDeGiroEjeZ > 90) {
Serial.print("a la derecha ");
motor1(100,0);
motor2(100,0);
 motor3(100,0);
 delay(1000);
}else{
Serial.print("a la izquierda");
motor1(100,1);
motor2(100,1);
motor3(100,1);
retraso(1000);

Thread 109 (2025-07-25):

Vision omnidireccional

3liasCo, 2025-07-25:
Los problemas son:

- como cortar el espejo o donde conseguirlo
- como saber la distancia de la pelota a la camara, usando el reflejo en el espejo

3liasCo, 2025-09-03:
https://github.com/user-attachments/assets/ae1115e4-45d9-4459-97c5-992641d4991c
13,30

sebalander, 2025-09-03:
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

coordenadas: (u,v)
A (102, 85)
B (213, 82)
C (256, 173)
D (57, 174)

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

3liasCo, 2025-09-09:
Matriz de homografia
[[ 6.19780830e-02 -5.03123896e-01  3.43223309e+02]
 [-1.03328294e+00  8.95598523e-02  1.68119733e+02]
 [ 2.82108774e-03  4.85037991e-02  1.00000000e+00]] [[1]
 [1]
 [1]
 [1]]

https://colab.research.google.com/drive/1xFGNJknGL935CIzn7urpsUH2Xfv8xPEG?usp=sharing

3liasCo, 2025-09-10:
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

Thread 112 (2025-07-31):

Charlas de Diseño 3D

Martii3141, 2025-07-31:
@mijaelb78 @vickyT049 como les dije la ultima clase, estaria bueno que por algun medio charlen entre ustedes de como van a hacer sus diseños, asi los diseños no se pisan entre si. Si quieren hacer una videollamada en algun momento entre ustedes para charlar entre ustedes este tipo de cosas, tambien es opcion. Si no por chat o por los mismos comentarios de este issue pueden ir diciendo lo que estan pensando en hacer y llegar a un acuerdo entre algunas cosas que seguro que van a aparecer en el medio.
Como recomendacion, si es que ya es algo mas que una idea y la estan ejecutando, tener las medidas a mano, alguna imagen, el mismo diseño en si, etc, para que de esa forma sea mucho mas visual para los dos.

mijaelb78, 2025-09-02:
@vickyT049 holaaa viki ya te subo la imagen  de la medida maxima de los pilares

mijaelb78, 2025-09-02:
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

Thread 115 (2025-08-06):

cinematica del robot zircon

sebalander, 2025-08-06:
@3liasCo te dejo algunas referencias que hemos encontrado sobre la cinematica del robot zircon de 3 ruedas.

[webmaster,+12282-Manuscrito-78114-1-6-20240322.pdf](https://github.com/user-attachments/files/21608861/webmaster.%2B12282-Manuscrito-78114-1-6-20240322.pdf)

[TFG_Jorge_Ramos_Perez_2020.pdf](https://github.com/user-attachments/files/21608866/TFG_Jorge_Ramos_Perez_2020.pdf)

[u295443.pdf](https://github.com/user-attachments/files/21608868/u295443.pdf)

@3liasCo sigamos por aca la discusion de la cinematica. podes postear vos lo que te dio chatgpt

3liasCo, 2025-08-09:
Hola! Tengo una cuestión sobre ¿como es que se va a comunicar el giroscopio con la teensy?. Le pregunté a una IA y me respondió esto:

BNO055          Teensy 4.1
VIN   --------> 3.3V
GND   --------> GND
SCL   --------> Pin 19 (SCL)
SDA   --------> Pin 18 (SDA)
ADR   --------> GND (dirección 0x28)

Dice que este tipo de comunicación se llama I²C.

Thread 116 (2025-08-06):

Investigación de los sensores infrarrojos Zircon

Aczino593, 2025-08-06:
Buenas profe. Necesito que me diga cual es el modelo de los 3 sensores infrarrojos que tiene instalado la Zircon para poder leer y hacer un código para estos sensores.
@sebalander

sebalander, 2025-08-07:
este esquematico de la Teensy/Zircon https://cdn.shopify.com/s/files/1/0892/9381/6107/files/Zircon.pdf

solo los llama "line sensors" y estoy buscando y no hay mas detalle sobre el modelo especifico de esos sensores.

pero lo importante es que hay disponible ejemplos https://robomov.net/blogs/zircon-tutorial/part-14

si aun eso no te alcanza, avisame y te busco mas. o tambien proba con alguna IA que te pase un codigo de ejemplo y lo discutimos por aca

Aczino593, 2025-09-09:
Base para modificar

#include <Arduino.h>
#include <zirconLib.h>

const int UMBRAL_BLANCO = 750; // ajustar con la cancha real
const int VELOCIDAD = 100;     // velocidad normal de movimiento
const int VELOCIDAD_CORR = 100; // velocidad durante corrección
const int TIEMPO_CORR = 400;   // tiempo para alejarse de la línea (ms)

void setup(void) {
  Serial.begin(9600);
  InitializeZircon();
}

void loop(void) {
  int s1 = readLine(1); // sensor lateral izquierdo
  int s2 = readLine(2); // sensor trasero
  int s3 = readLine(3); // sensor lateral derecho

  // --- Muestra valores para calibrar ---
  Serial.print("S1: "); Serial.print(s1);
  Serial.print("\tS2: "); Serial.print(s2);
  Serial.print("\tS3: "); Serial.print(s3);

  // --- Lógica de escape ---
  if (s1 > UMBRAL_BLANCO) {
    Serial.print("\t--> Línea blanca IZQUIERDA, giro DERECHA");
    motor1(VELOCIDAD_CORR, 1); // rueda derecha atrás
    motor3(VELOCIDAD_CORR, 1); // rueda izquierda adelante
    delay(TIEMPO_CORR);
  }
  else if (s3 > UMBRAL_BLANCO) {
    Serial.print("\t--> Línea blanca DERECHA, giro IZQUIERDA");
    motor1(VELOCIDAD_CORR, 0); // rueda derecha adelante
    motor3(VELOCIDAD_CORR, 0); // rueda izquierda atrás
    delay(TIEMPO_CORR);
  }
  else if (s2 > UMBRAL_BLANCO) {
    Serial.print("\t--> Línea blanca ATRÁS, avanzo al frente");
    motor1(VELOCIDAD_CORR, 0);
    motor3(VELOCIDAD_CORR, 1);
    delay(TIEMPO_CORR);
  }

  // --- Movimiento normal (seguir jugando) ---
  motor1(VELOCIDAD, 0);
  motor3(VELOCIDAD, 1);

  Serial.println();
  delay(50); // pequeño delay para estabilidad
}

Aczino593, 2025-09-16:
Base a probar:

#include <Arduino.h>
#include <zirconLib.h>

const int UMBRAL_BLANCO = 750;   // Línea blanca
const int UMBRAL_VERDE_MIN = 300; //  verde (ajustar según valores reales)
const int UMBRAL_VERDE_MAX = 700;

int direccion = 1; // 1 = derecha, 0 = izquierda

void setup(void) {
  Serial.begin(9600);
  InitializeZircon();
}

void loop(void) {
  int s1 = readLine(1); // Izquierda
  int s2 = readLine(2); // Centro
  int s3 = readLine(3); // Derecha

  Serial.print("S1: "); Serial.print(s1);
  Serial.print("\tS2: "); Serial.print(s2);
  Serial.print("\tS3: "); Serial.print(s3);

  bool blanco_izq = s1 > UMBRAL_BLANCO;
  bool blanco_der = s3 > UMBRAL_BLANCO;

  bool verde_izq = s1 >= UMBRAL_VERDE_MIN && s1 <= UMBRAL_VERDE_MAX;
  bool verde_cen = s2 >= UMBRAL_VERDE_MIN && s2 <= UMBRAL_VERDE_MAX;
  bool verde_der = s3 >= UMBRAL_VERDE_MIN && s3 <= UMBRAL_VERDE_MAX;

  if (blanco_izq && !blanco_der) {
    // cerca del borde izquierdo, girar a la derecha
    direccion = 1;
    motor1(100, 1); // Motor izquierdo atrás
    motor3(100, 0); // Motor derecho adelante
    Serial.print("\tGirando a la derecha");
  }
  else if (blanco_der && !blanco_izq) {
    // Cerca del borde derecho, girar a la izquierda
    direccion = 0;
    motor1(100, 0); // Motor izquierdo adelante
    motor3(100, 1); // Motor derecho atrás
    Serial.print("\tGirando a la izquierda");
  }
  else if (verde_izq && verde_cen && verde_der) {
    // Dentro del área, seguir patrullando en la dirección actual
    if (direccion == 1) {
      motor1(100, 1); // Ir a la derecha
      motor3(100, 1);
      Serial.print("\tPatrullando derecha");
    } else {
      motor1(100, 0); // Ir a la izquierda
      motor3(100, 0);
      Serial.print("\tPatrullando izquierda");
    }
  }
  else {
    // Caso inesperado (fuera del área, negro, etc.)
    motor1(0, 0);
    motor3(0, 0);
    Serial.print("\t[ALERTA] Fuera de zona segura");
  }

  Serial.println();
  delay(100);
}

Aczino593, 2025-09-16:
Medicion umbrales:

#include <Arduino.h>
#include <zirconLib.h>

const int UMBRAL_BLANCO = 750; // Línea blanca
const int UMBRAL_VERDE_MIN = 300; // verde (ajustar según valores reales)
const int UMBRAL_VERDE_MAX = 700;

int direccion = 1; // 1 = derecha, 0 = izquierda

void setup(void) {
Serial.begin(9600);
InitializeZircon();
}

void loop(void) {
int s1 = readLine(1); // Izquierda
int s2 = readLine(2); // Centro
int s3 = readLine(3); // Derecha

Serial.print("S1: "); Serial.print(s1);
//Serial.print("\tS2: "); Serial.print(s2);
//Serial.print("\tS3: "); Serial.print(s3);

//bool blanco_izq = s1 > UMBRAL_BLANCO;
//bool blanco_der = s3 > UMBRAL_BLANCO;
//
//bool verde_izq = s1 >= UMBRAL_VERDE_MIN && s1 <= UMBRAL_VERDE_MAX;
//bool verde_cen = s2 >= UMBRAL_VERDE_MIN && s2 <= UMBRAL_VERDE_MAX;
//bool verde_der = s3 >= UMBRAL_VERDE_MIN && s3 <= UMBRAL_VERDE_MAX;
//
//if (blanco_izq && !blanco_der) {
//// cerca del borde izquierdo, girar a la derecha
//direccion = 1;
//motor1(100, 1); // Motor izquierdo atrás
//motor3(100, 0); // Motor derecho adelante
//Serial.print("\tGirando a la derecha");
//}
//else if (blanco_der && !blanco_izq) {
//// Cerca del borde derecho, girar a la izquierda
//direccion = 0;
//motor1(100, 0); // Motor izquierdo adelante
//motor3(100, 1); // Motor derecho atrás
//Serial.print("\tGirando a la izquierda");
//}
//else if (verde_izq && verde_cen && verde_der) {
//// Dentro del área, seguir patrullando en la dirección actual
//if (direccion == 1) {
//motor1(100, 1); // Ir a la derecha
//motor3(100, 1);
//Serial.print("\tPatrullando derecha");
//} else {
//motor1(100, 0); // Ir a la izquierda
//motor3(100, 0);
//Serial.print("\tPatrullando izquierda");
//}
//}
//else {
//// Caso inesperado (fuera del área, negro, etc.)
//motor1(0, 0);
//motor3(0, 0);
//Serial.print("\t[ALERTA] Fuera de zona segura");
//}
//
//Serial.println();
//delay(100);
}

Aczino593, 2025-10-05:
Detector de linea del modo delantero:

#include <Arduino.h>
#include <zirconLib.h>

float mover(float centimetros, int eje) {
  float tiempo = abs(((0.0654 * centimetros) - 0.1785) * 1000);
   if (centimetros>=0){
    if (eje == 3) {
      motor1(100, 0);
      motor2(100, 1);
      delay(tiempo);
      motor1(0, 0);
      motor2(0, 1);
    }
    else if (eje == 1) {
      motor3(100, 0);
      motor2(100, 1);
      delay(tiempo);
      motor3(0, 0);
      motor2(0, 1);
    }
    else if (eje == 2) {
      motor3(100, 0);
      motor1(100, 1);
      delay(tiempo);
      motor3(0, 0);
      motor1(0, 1);
    }
   }
   else {
    if (eje == 3) {
      motor1(100, 1);
      motor2(100, 0);
      delay(tiempo);
      motor1(0, 1);
      motor2(0, 0);
    }
    else if (eje == 1) {
      motor3(100, 1);
      motor2(100, 0);
      delay(tiempo);
      motor3(0, 1);
      motor2(0, 0);
    }
    else if (eje == 2) {
      motor3(100, 1);
      motor1(100, 0);
      delay(tiempo);
      motor3(0, 1);
      motor1(0, 0);
    }
   }
  return tiempo;
}

float girar(float angulo) {
  float tiempo = abs(angulo * 50 / 47.0);

   if (angulo>=0){
    motor1(100, 1);
    motor2(100, 1);
    motor3(100, 1);
    delay(tiempo);
    motor1(0, 1);
    motor2(0, 1);
    motor3(0, 1);
   }
   else {
    motor1(100, 0);
    motor2(100, 0);
    motor3(100, 0);
    delay(tiempo);
    motor1(0, 0);
    motor2(0, 0);
    motor3(0, 0);
   }
  return tiempo;
}
// -----------------------------------------------------------------------------------------

const int VELOCIDAD_CRUISE = 70;   // velocidad para avanzar normalmente
const int TIEMPO_POST_GIRO = 120;  // ms (pequeña pausa tras girar antes de avanzar)

// --- Rangos de color o umbral
bool esBlancoS1(int v){ return (v >= 575) && (v <= 753); }
bool esVerdeS1 (int v){ return (v >= 210) && (v <= 340); }

bool esBlancoS2(int v){ return (v >= 494) && (v <= 762); }
bool esVerdeS2 (int v){ return (v >= 370) && (v <= 467); }

bool esBlancoS3(int v){ return (v >= 766) && (v <= 780); }
bool esVerdeS3 (int v){ return (v >= 254) && (v <= 342); }

void setup() {
  InitializeZircon();
  Serial.begin(115200);
  delay(200);
}

void loop() {
  // leer sensores
  int s1 = readLine(1); // izquierda
  int s2 = readLine(2); // centro
  int s3 = readLine(3); // derecha

  // imprimir para calibración
  Serial.print("S1:"); Serial.print(s1);
  Serial.print(" S2:"); Serial.print(s2);
  Serial.print(" S3:"); Serial.print(s3);

  bool blanco_s1 = esBlancoS1(s1);
  bool verde_s1  = esVerdeS1(s1);
  bool blanco_s2 = esBlancoS2(s2);
  bool verde_s2  = esVerdeS2(s2);
  bool blanco_s3 = esBlancoS3(s3);
  bool verde_s3  = esVerdeS3(s3);

  // --- Si un sensor ve blanco y los otros 2 verde -> ejecutar giro ---
  if (blanco_s1 && verde_s2 && verde_s3) {
    Serial.println("\tDetectado: BLANCO IZQUIERDA -> giro (alejarse)");
    girar(-45.0);
    delay(TIEMPO_POST_GIRO);
  }
  else if (blanco_s3 && verde_s2 && verde_s1) {
    Serial.println("\tDetectado: BLANCO DERECHA -> giro (alejarse)");
    girar(45.0);
    delay(TIEMPO_POST_GIRO);
  }
  else if (blanco_s2 && verde_s1 && verde_s3) {
    Serial.println("\tDetectado: BLANCO CENTRO -> giro 180 (o retroceder)");
    // opción 1: girar 180
    girar(180.0);
    delay(TIEMPO_POST_GIRO);
  }
  else {
    // --- Caso normal: todo verde -> avanzar continuamente ---
    Serial.println("\tTodo verde -> avanzando");
    // Para avanzar continuo usamos las mismas llamadas que usa mover() en adelante.
    // Ajusta direcciones si tu mapping es distinto.
    motor1(VELOCIDAD_CRUISE, 0); // ejemplo: motor1 adelante
    motor2(VELOCIDAD_CRUISE, 1); // ejemplo: motor2 adelante
    motor3(VELOCIDAD_CRUISE, 0); // si tu robot usa 3 motores para avanzar, mantener consistencia
  }

  delay(80); // pequeño retardo para estabilidad
}

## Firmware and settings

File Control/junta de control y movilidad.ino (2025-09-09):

// Incluir la librería de Serial para Teensy
#include <Arduino.h>
#include <zirconLib.h>
int potencia=90;

float mover(float centimetros, int eje) {
  float tiempo = abs(((0.0654 * centimetros) - 0.1785) * 1000);
  if (centimetros >= 0) {
    if (eje == 3) {
      motor1(100, 0);  //adelante   // izquierda 
      motor2(100, 1);
      delay(tiempo);
      motor1(0, 0);
      motor2(0, 1);
    }
    else if (eje == 1) {
      motor3(100, 0);    //adelante   // al frente 
      motor2(100, 1);
      delay(tiempo);
      motor3(0, 0);
      motor2(0, 1);
    }
    else if (eje == 2) {
      motor3(100, 0);    //adelante // derecha 
      motor1(100, 1);
      delay(tiempo);
      motor3(0, 0);
      motor1(0, 1);
    }
  }
  else
  {
    if (eje == 3) {
      motor1(100, 1);
      motor2(100, 0);
      delay(tiempo);
      motor1(0, 1);
      motor2(0, 0);
    }
    else if (eje == 1) {
      motor3(100, 1);
      motor2(100, 0);
      delay(tiempo);
      motor3(0, 1);
      motor2(0, 0);
    }
    else if (eje == 2) {
      motor3(100, 1);
      motor1(100, 0);
      delay(tiempo);
      motor3(0, 1);
      motor1(0, 0);
    }
  }

  return tiempo;
}

float girar(float angulo) {
  float tiempo = abs(angulo * 43 / 200);

  if (angulo > 0) { 
    motor1(potencia, 0);
    motor2(potencia, 0);
    motor3(potencia, 0);
    delay(tiempo);
    motor1(0, 0);
    motor2(0, 0);
    motor3(0, 0);
  }
  else
  {
    motor1(potencia, 1);
    motor2(potencia, 1);
    motor3(potencia, 1);
    delay(tiempo);
    motor1(0, 1);
    motor2(0, 1);
    motor3(0, 1);
  }
  return tiempo;
}

// Definir los pines UART que se usarán. UART3 en OpenMV generalmente se mapea a Serial1 en Teensy.
// Asegúrate de que los pines RX y TX en tu Teensy 4.1 estén conectados correctamente a los pines TX y RX del OpenMV.
// Para Teensy 4.1, Serial1 usa pines 0 (RX1) y 1 (TX1).
// Si necesitas usar otro puerto serial, como Serial2, Serial3, etc., consulta el pinout de tu Teensy 4.1.
#define RX_PIN 0 // Pin RX1 en Teensy 4.1
#define TX_PIN 1 // Pin TX1 en Teensy 4.1

// Velocidad de comunicación serial (baudios)
const long BAUD_RATE = 19200;

// Variables para almacenar los datos decodificados
float decodedX = 0.0;
float decodedY = 0.0;
float decodedAngle = 0.0;
int decodedSense = 0; // Variable para el sentido

// Estados para la máquina de estados del decodificador
enum DecoderState {
  WAITING_FOR_HEADER,
  READING_BYTE_X,
  READING_BYTE_Y,
  READING_BYTE_ANGLE,
  READING_SENTIDO // Nuevo estado para el sentido
};

DecoderState currentState = WAITING_FOR_HEADER;

void setup() {
  InitializeZircon(); // Inicializa la librería Zirco

  // Inicializar la comunicación serial para depuración (monitor serial de Arduino IDE)
  Serial.begin(BAUD_RATE);
  while (!Serial && millis() < 5000); // Esperar a que el monitor serial se conecte (solo para placas con USB nativo)
  Serial.println("Decodificador Teensy iniciado.");

  // Inicializar la comunicación serial para recibir datos del OpenMV
  // Usamos Serial1 para UART3 del OpenMV
  Serial1.begin(BAUD_RATE);
  Serial.println("Serial1 (UART) iniciado.");
}

void loop() {
  // Comprobar si hay bytes disponibles para leer en el puerto serial del OpenMV
  if (Serial1.available()) {
    int incomingByte = Serial1.read(); // Leer el byte entrante

    // *** Importante para depuración: Imprimir cada byte recibido ***
    Serial.print("Byte recibido: ");
    Serial.println(incomingByte);

    // Máquina de estados para decodificar el paquete
    switch (currentState) {
      case WAITING_FOR_HEADER:
        // Si el byte recibido es un encabezado, cambiar al estado de lectura de datos
        if (incomingByte == 201) {
          currentState = READING_BYTE_X;
        } else if (incomingByte == 202) {
          currentState = READING_BYTE_Y;
        } else if (incomingByte == 203) {
          currentState = READING_BYTE_ANGLE;
        } else if (incomingByte == 204) { // Encabezado para 'sentido'
          currentState = READING_SENTIDO;
        }
        // Si el byte no es un encabezado conocido, se ignora y se espera el siguiente byte
        break;

      case READING_BYTE_X:
        // Decodificar X: byteX (0-200) -> X (0-100 cm)
        decodedX = (float)incomingByte / 2.0;
        Serial.print("  -> X (byte): "); Serial.print(incomingByte);
        Serial.print(" -> X (cm): "); Serial.println(decodedX, 2); // Imprimir con 2 decimales
        currentState = WAITING_FOR_HEADER; // Volver a esperar un encabezado
        break;

      case READING_BYTE_Y:
        // Decodificar Y: byteY (0-200) -> Y (-50 a 50 cm)
        // La fórmula de tu OpenMV es (Y + 50) * 2, así que la inversa es (byteY / 2) - 50
        decodedY = ((float)incomingByte / 2.0) - 50.0;
        Serial.print("  -> Y (byte): "); Serial.print(incomingByte);
        Serial.print(" -> Y (cm): "); Serial.println(decodedY, 2);
        currentState = WAITING_FOR_HEADER;
        break;

      case READING_BYTE_ANGLE:
        // Decodificar Ángulo: byteAng (0-200) -> Ángulo (-100 a 100 grados)
        // La fórmula de tu OpenMV es angulo + 100, así que la inversa es byteAng - 100
        decodedAngle = (float)incomingByte - 100.0;
        Serial.print("  -> Angulo (byte): "); Serial.print(incomingByte);
        Serial.print(" -> Angulo (grados): "); Serial.println(decodedAngle, 2);
        girar(decodedAngle);
        currentState = WAITING_FOR_HEADER;
        break;

      case READING_SENTIDO:
        // Decodificar Sentido: sentido (0 o 1)
        // El valor se envía directamente, no necesita escalado inverso
        decodedSense = incomingByte;
        Serial.print("  -> Sentido (byte): "); Serial.print(incomingByte);
        Serial.print(" -> Sentido: "); Serial.println(decodedSense);
        Serial.println("--- Paquete completo decodificado ---"); // Indicador de paquete completo
        currentState = WAITING_FOR_HEADER;
        break;
     
    }
  }
}

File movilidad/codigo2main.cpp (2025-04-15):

#include <Arduino.h>
#include <zirconLib.h>


void setup(void)
{
  Serial.begin(9600);

  InitializeZircon();

}


void loop(void)
{   
    //Definiciom de variables
    int v1;     //Potencia del motor 1
    v1=100; //velocidad
    //v1=100 que es la potencia 
    for(v1=255; v1>=0; v1=v1-10){ //esto si funciona 
      Serial.print("v1: ");
      Serial.println(v1);
      motor1(v1, 1);
      delay(1000);
    }
    
}

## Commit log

2025-04-29 agregar transformacion a esfericas y enviar eso por monitor serie
    agregue una tranformada de x,y,z a coordenadas esfericas respecto al centro de masa del atractor. el centro de masa se calcula como un promedio movil. el mensaje de salida ahora tambien tiene el tiem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
2025-04-30 calculo del angulo con signos invertidos
    con m libre
    m: eje de la camara a el medio de la imagen
2025-05-01 agregar una fuente de problemas de matematica
2025-05-06 Update nombre bonito.py
    calcula el angulo adaptandose a las necesidades del control
    0 si es en sentido horario
    1 si es antihorario
2025-05-20 Create Prueba de giroscopo 🙂
    Trate de probar el giroscopo pero creó que hay un fallo 😞
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2025-05-20 Update nombre bonito.py
    ahora dice si
    encontro la pelota
    mapea la cordenada x de 0 a 100
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2025-05-28 Create calibrar-distancia
    calibrar la distancia que recorre el robot en cuanto al tiempo
2025-05-28 Create funciones-de-movimiento
    codigo que utilizaremos para determinar la direccion a donde ira el robot y canto distancia recorrera en cm
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2025-05-30 Create rxtx_listener.ino to read bytes from rxtx and print them on serialmonitor
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2025-06-03 Create giro-por-tiempo-del-robot
    dependiendo del angulo realiza una regla de tres simples, y obtiene el tiempo para que el robot se mueva al angulo deseado
    problema: los motores se mueven fuera de la funcion
2025-06-03 esclavo_y_arquero_Desplazamiento_lateral
    es un esclavo que recieve datos de la "open mv" de angulo y distancia y con eso crea Desplazamiento lateral
2025-06-03 Create modo_delantero
    codigo de base para el modo delantero ( mover en direccion arriba, abajo, iizquuierda, derecha, tratar de meter gol )
2025-06-04 subir STL iejos que tenia del Dribbler
    [Glorious Fyyran-Fulffy.stl, Ingenious Vihelmo-Esboo.stl, Smashing Jofo.stl]
2025-06-10 diseño.pisodecamar
    ns
    [Daring Hango-Fyyran (1).stl]
2025-06-10 piso.decamara
    el piso que realice deje aberturas para la union de las torres (:
    [Terrific Albar-Bruticus (3).stl]
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2025-06-10 correccion de base
    jajajja
    [Neat Stantia-Duup.stl]
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2025-06-24 Add files via upload
    Diseño de un cilindro dirigido al dribbler, con la funcion de retener la pelota
    [Cilindro (normal).stl]
2025-06-24 estructura para los pisos
    [estructura para los pisos.stl]
2025-06-24 Add files via upload
    Mismo cilindro pero con reduccion en el centro para que pueda contener mejor la pelota
    [Cilindro (forma de reloj de arena).stl]
2025-06-24 Add files via upload
    Mismo cilindro pero con reducción en el centro para que pueda contener mejor la pelota.
    [Cilindro (forma de reloj de arena).stl]
2025-06-25 Rename n to n
    cuando mira la pelota tira este error
    TypeError: can't convert float to int
    cuando no la mira
    NameError: name 'X' isn't defined
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2025-07-01 base0.3
    esta es mi ultimo modelo de la base para la camara
    [base-0.3demijael.stl]
2025-07-01 Update and rename OpenMV/n to enviar paq. de datos
    dos errores arreglados
2025-07-01 Rename enviar paq. de datos to enviar paq. de datos
    dos errores arreglados pero la camara baja los fps cuando detecta la pelota
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2025-07-02 Rename enviar paquete de datos to enviar paquete de datos
    arregle el error de los fps bajos pero todavia no se cual era el error
    lo que falta hacer es una cuestion de conectar bien las cosas en la placa y la proxima clase tengo que hacer una base para la camara y calibrarla
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2025-07-16 Rename gemini to UART Teensy recibe datos y los imprime en la terminal
    Entrar a Arduino y cambiar de serial en herramientas a COM04
    Por ahora solo recibe la parte entera de los datos, no los redondea si eso afecta en la exactitud arreglar
2025-07-21 ultimo diceño de camara
    [Grand Stantia-Turing (1).stl]
2025-07-22 soporte de camara como una placa inclinada con agujeros
    [Fabulous Lappi.stl]
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2025-07-22 intento3D-patilla
    jdbjcfhiouqah
    [mijael.barra.stl]
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2025-07-23 soporte para motor amarillo modificado para evitar interferencias
    [soporte TT motor_recortado 2025-07-23 - seba.scad, soporte TT motor_recortado 2025-07-23 - seba.stl]
2025-07-23 modificar los orificios para tornillos y recortar una fraccion del modelo para testeo
    [soporte TT motor_recortado 2025-07-23 - seba.scad, soporte TT motor_recortado 2025-07-23 - seba.stl]
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2025-07-24 luego de testear, imprimo el soporte completo
    [soporte TT motor_recortado 2025-07-23 - seba.scad, soporte TT motor_recortado 2025-07-23 - seba.stl]
2025-07-25 Add files via upload
    primer diseño de la estructura del remate estructural
    [Grand Jaagub-Bigery.stl]
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2025-07-30 cilindro de dribbler con diente en el eje para evitar giro del eje LEGO
    [Cilindro (forma de reloj de arena) con diente en el eje.scad, Cilindro (forma de reloj de arena) con diente en el eje.stl]
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2025-08-05 huecos para la camara prueba
    [Fabulous Luulia-Robo.stl]
2025-08-05 Add files via upload
    diseño del soporte de fachada estructural , va por debajo de la tensy
    [Fantabulous Jaban-Turing.stl]
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2025-08-05 soporte de fachada estructural
    [Fantabulous Jaban-Turing (2).stl]
2025-08-05 base para cámara ultimo modelo
    [Daring Jaagub-Fyyran.stl]
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2025-08-19 diseño de la base
    [Fantabulous Jaban-Turing (4).stl]
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2025-08-19 la union de los diseños
    uni el diseño de viki con el mio para ponerlos en la zircon
    [union diseño de v+m.stl]
2025-08-19 union de los diseños de camara y soporte
    uni el diseño de viki (union a zircon)
    con el mio (soporte de camara)
    [Tremendous Allis.stl]
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2025-08-26 modelo de soporte de camara definido
    [Funky Elzing-Gaaris (2).stl]
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2025-09-02 base estructural
    mejorada y mas alta
    [Fantabulous Jaban-Turing (5).stl]
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2025-09-12 zircon stl to print a mock zircon base
    [motor_p_imprimir.stl, rueda_p_imprimir.stl]
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2025-09-16 modelos scad y stl de solenoide para kicker
    [solenoide.scad, solenoide.stl]
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2025-09-17 Create UART Teensy corregido
    Creo que pudo haber un error en el código anterior de la teensy que recibía los datos. El código anterior tenia la máquina de estados mal sincronizada con los paquetes, esperaba que cada byte de encabezado llegue de manera aislada y cambiaba de estado inmediatamente, esto hacia que se salte valores de bytes o que se desordenen, que es lo veía la clase pasada.
    Ahora espera los 8 bytes del paquete antes de decodificar.
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2025-09-18 valores de cada color en los sensores
    [valores de los sensores.xlsx]
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2025-09-23 diseño definitivo del soporte de camara
    [Funky Elzing-Gaaris.stl]
2025-09-23 remodelación de los pilares
    [Brilliant Waasa-Gaaris (1).stl]
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2025-10-01 Update para que persiga la pelota
    - Hay un problema con la comunicación con la cámara, no entra al
    " if (header1 == 201 && header2 == 202 && header3 == 203 && header4 == 204) "
    no funciona con este codigo ni con el del domingo que funcionaba, por lo que debe ser un problema de hardware.
    - La funcion girar activa los motores durante un momento muy corto no llega a realizar la cantidad de grados que se le pide, probablemente algun problema con millis
    - Colocar los cambios de estados dentro del switch
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2025-10-14 base de zircon con gias
    [Amazing Wluff (4).stl]
2025-10-15 14 de octubre diseño de estructura
    este diseño es el encargado de cubrir la luces
    [Amazing Wluff (10).stl]
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
